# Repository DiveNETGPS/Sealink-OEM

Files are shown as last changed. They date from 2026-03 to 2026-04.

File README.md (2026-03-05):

# DiveNET: Sealink-OEM

Repository landing page and navigation.

## Where to start

- Product docs and source bundle: [product/](product/)
- Main product overview: [product/README.md](product/README.md)
- Requirements and options: [product/Sealink-OEM_Requirements_and_Options.md](product/Sealink-OEM_Requirements_and_Options.md)
- Integrator/testing process guide: [product/integrations/PLATFORM_INTEGRATOR_GUIDE.md](product/integrations/PLATFORM_INTEGRATOR_GUIDE.md)

## Repository layout

- `product/` contains the current documentation and integration content.
- Root-level build/release scripts (`*.bat`, `*.spec`, `VERSION.txt`) are packaging utilities.
- `release/` and `release_assets/` hold generated/customer-facing distribution assets.

---
Questions or support? Contact DiveNET: support@divenetgps.com
Last updated: March 2026

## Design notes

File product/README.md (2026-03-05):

# DiveNET: Sealink-OEM Subsea Wireless Modem

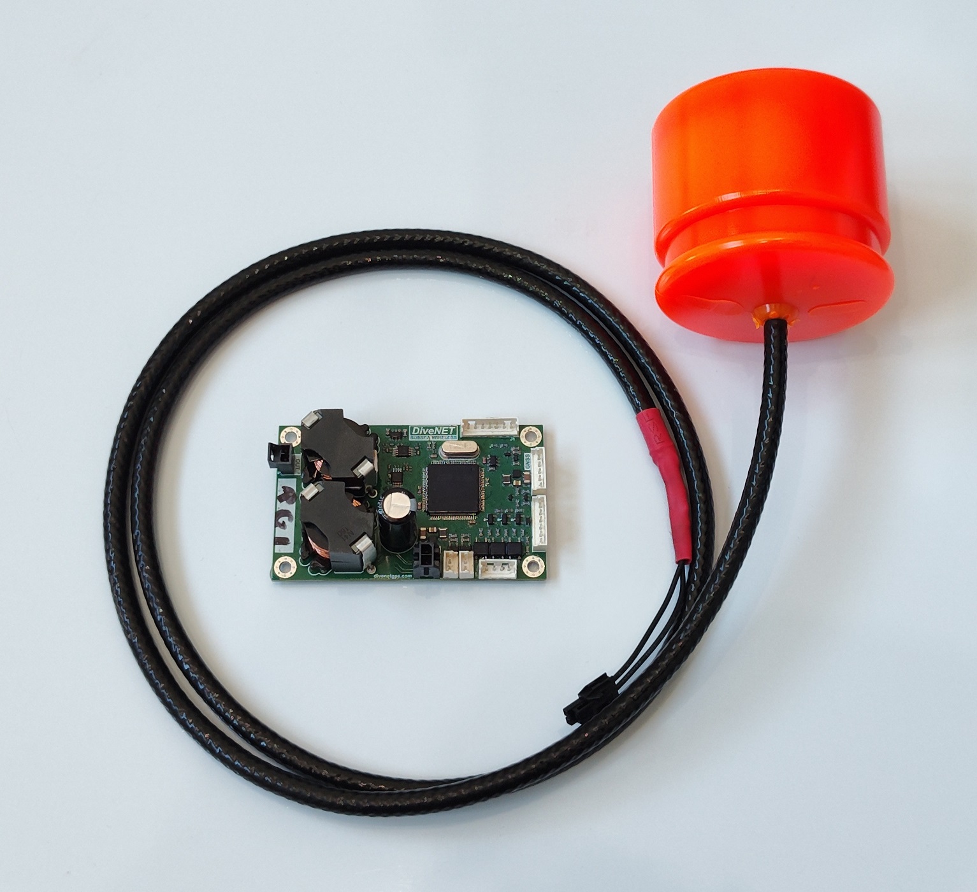
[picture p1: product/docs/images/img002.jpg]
Sealink-OEM


**Sealink-OEM** is a compact, high-reliability underwater acoustic modem and communication platform produced by DiveNET Subsea Wireless (Beringia Enterprises LLC).

### Key Features
- Extremely compact PCB: 73.5 mm × 44 mm
- Reliable long-range communication
- Multi-mode functionality
- Communication envelope up to 3,000 m / 1,000 m depth (transducer-dependent)
- Up to 634 bps bandwidth
- 255 logical addresses (responders) and 20 code channels
- 9600 bps UART interface (3.3 V logic)
- Built-in support for external pressure/temperature sensor (I²C on XP6)
- GNSS and RF module expansion
- Built-in Time-of-Flight (ToF) ranging with ~0.15 m resolution
- Tx/Rx strobe output for external timestamp capture
- Designed to power subsea IoT and professional ROV/AUV/Diver applications

### Primary Specifications
- **Board size**: 73.5 mm × 44 mm
- **Power**: +12 V DC nominal
- **Logic level**: 3.3 V UART (0–3.3 V)
- **UART settings**: 9600 baud, 8N1 (default)
- **Connectors**: Molex Mini-Fit Jr. series
- **Operating modes**: Transparent channel, Command mode, Packet mode
- **Ranging**: ~0.15 m resolution (acoustic detection limit)

### Transducer Options
Sealink-OEM supports interchangeable transducers for different mission profiles:

1. **1,000 m acoustic range / 600 m depth rating**  
   - Model: SW-T100  
   - Max slant range: ~1,000 m (line-of-sight)  
   - Max operational depth: 600 m  
   - [Specification]

2. **3,000 m acoustic range / 300 m depth rating**  
   - Model: SW-T200    
   - Max slant range: ~3,000 m (line-of-sight)  
   - Max operational depth: 300 m  
   - [Specification]

3. **3,000 m acoustic range / 1,000 m depth rating**  
   - Model: SW-T300    
   - Max slant range: ~3,000 m (line-of-sight)  
   - Max operational depth: 1,000 m  
   - [Specification]

### Quick Start
1. Connect power (+12 V nominal) to XP2 and transducer to XP1.  
2. Use any serial terminal (PuTTY, Tera Term, CoolTerm, minicom) at 9600 8N1.  
3. Send `$PUWV2,0,0,0*2A` to ping a remote unit.  
- Expect an immediate `$PUWV0` automatic acknowledgement response (e.g., `$PUWV0,2,0*XX`) confirming command acceptance. If errCode ≠ 0, check setup.
4. Receive main response `$PUWV3,0,0,propTime,MSR*hh` → approximate range = propTime (seconds) × 1500 (m/s).  
5. Refine with correct sound speed (adjust for temperature/salinity/depth).

Full documentation → see [docs](docs) folder.

### Documentation Map

- [Documentation Index](docs/README.md)

### Modem Documentation

- [Getting Started](docs/Sealink-OEM_Getting_Started.md)
- [Pinout & Interface](docs/Sealink-OEM_Pinout_and_Interface.md)
- [Communication Protocol](docs/Sealink-OEM_Communication_Protocol.md)
- [Basic Ranging Guide](docs/Sealink-OEM_Basic_Ranging_Guide.md)
- [Technical Drawing](docs/Sealink-OEM_Technical_Drawing.pdf)

### Utility App Documentation

- [Sealink-OEM Utility App Guide](docs/Sealink-OEM_Utility_App_Guide.md)
- [CLI test script](resources/uart-getRange.py)

---
Questions or support? Contact DiveNET: support@divenetgps.com
Last updated: March 2026

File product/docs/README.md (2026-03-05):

# Sealink-OEM Documentation Index

Use this index to navigate modem documentation and software tooling guides.

## Modem Fundamentals

- [Getting Started](Sealink-OEM_Getting_Started.md)
- [Pinout and Interface](Sealink-OEM_Pinout_and_Interface.md)
- [Communication Protocol](Sealink-OEM_Communication_Protocol.md)
- [Basic Ranging Guide](Sealink-OEM_Basic_Ranging_Guide.md)
- [Technical Drawing (PDF)](Sealink-OEM_Technical_Drawing.pdf)

## Utility App and Tools

- [Sealink-OEM Utility App Guide](Sealink-OEM_Utility_App_Guide.md)
- [CLI test script (uart-getRange.py)](../resources/uart-getRange.py)

## Integration References

- [Integrator Platform Guide](../integrations/PLATFORM_INTEGRATOR_GUIDE.md)
- [Arduino Example](../integrations/arduino/SealinkOEM_Basic.ino)
- [Raspberry Pi CLI Runner](../integrations/raspberry-pi/run_sealink_cli.sh)

---
Questions or support? Contact DiveNET: support@divenetgps.com
Last updated: March 2026

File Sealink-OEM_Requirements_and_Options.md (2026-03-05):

# Sealink-OEM – Requirements and Options

This root-level file is retained for compatibility.

## Minimum Host Requirements (Summary)

### Windows Native Utility Package
- Package: Sealink-OEM (Windows Utility package)
- OS: Windows 10 or Windows 11 (64-bit)
- Python: not required for packaged `.exe` execution
- Serial access: at least one available `COM` port through compatible USB-UART bridge or host UART interface

### Integrator / CLI Workflow
- Package: Sealink-Integrator-Pack (CLI/Integration)
- Python: 3.10 or newer (3.10–3.12 recommended)
- `pip` and dependency install from `resources/requirements.txt` (includes `pyserial`)
- Linux/Raspberry Pi workflow uses `integrations/raspberry-pi/run_sealink_cli.sh`

Current maintained version:

- [product/Sealink-OEM_Requirements_and_Options.md](product/Sealink-OEM_Requirements_and_Options.md)

Use the file above for current requirements and options guidance.

---
Questions or support? Contact DiveNET: support@divenetgps.com
Last updated: March 2026

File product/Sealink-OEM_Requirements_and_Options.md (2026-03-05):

# Sealink-OEM – Requirements and Options

This document summarizes the **mandatory requirements** for operating the Sealink-OEM modem and the **optional/configurable elements** available to adapt it to different applications.

## Mandatory Requirements

### Host Software Requirements (Native App and Integrator Workflows)

#### Windows Native Utility Package
- Package: Sealink-OEM (Windows Utility package)
- OS: Windows 10 or Windows 11 (64-bit)
- Python: not required for packaged `.exe` execution
- Serial access: at least one available `COM` port through compatible USB-UART bridge or host UART interface

#### Integrator / CLI Workflow
- Package: Sealink-Integrator-Pack (CLI/Integration)
- Python: 3.10 or newer (3.10–3.12 recommended)
- Required Python dependency set from `resources/requirements.txt` (includes `pyserial`)
- Linux/Raspberry Pi workflow requires shell access for `integrations/raspberry-pi/run_sealink_cli.sh`

### Power Supply
- Voltage: +12 V DC nominal  
- Range: 12 V minimum – 14 V maximum (±0.3 V tolerance)  
- Connector: XP2 (Molex 43045-0212)  
  - Pin 1: GND  
  - Pin 2: +12 V  
- **Caution**: Exceeding 14.3 V or dropping below 12 V may damage the board or cause unreliable operation.

### Communication Interface
- UART: 9600 baud, 8 data bits, no parity, 1 stop bit (8N1)  
- Logic level: 0–3.3 V (do not exceed 3.3 V on data lines)  
- Connector: XP5 (Molex 53253-0470)  
  - Pin 1: TxD  
  - Pin 2: RxD  
  - Pin 3: SVC/CMD (strobe output in firmware ≥1.2.0)  
  - Pin 4: GND  
- **Caution**: Applying >5.3 V to UART lines will cause automatic shutdown or permanent damage.

### Acoustic Transducer
- Must be connected to XP1 (Molex 105309-1102)  
- Use only the transducer supplied with the device or a compatible model (SW-T100, SW-T200, SW-T300)  
- **Caution**: Using a non-compatible antenna/transducer will result in damage to the board.

### Operating Environment
- The modem is designed for underwater/submerged use.  
- Dry-land testing is supported only for basic functional verification (transducers within ~6 inches).  
- **Note**: Dry-land operation does not guarantee payload data integrity.

### Firmware
- Minimum version: ≥1.2.0 (command mode always enabled, SVC/CMD repurposed as strobe output)

## Optional / Configurable Elements

### Transducer Selection
Choose based on range vs. depth trade-off:

| Model | Max Acoustic Range (slant) | Max Operational Depth | Notes |
|---|---|---|---|
| SW-T100 | ~1,000 m | 600 m | Best for moderate range / deeper ops |
| SW-T200 | ~3,000 m | 300 m | Balanced range / depth |
| SW-T300 | ~3,000 m | 1,000 m | Maximum range + maximum depth |

### Expansion Modules
- **XP6 – Pressure Sensor**  
  - Designed specifically for KELLER 4LD series (I²C)  
  - Pinout: +3.3 V, SDA, SCL, GND  
  - **Caution**: Connecting any other device is prohibited and may cause permanent failure.

- **XP7 – GNSS Module**  
  - +3.3 V, 1PPS, TxD, RxD, GND  
  - For optional position/time synchronization

- **XP8 – RF Module**  
  - +5 V, ENABLE, TxD, RxD, GND, SET  
  - For optional surface RF gateway/relay

### LED Indicators
- Connected via XP3/XP4 (LED +, LED -)  
- Can be used for status visualization (power, Tx/Rx activity, etc.)

### Sound Speed for Ranging
- Default in examples/scripts: 1500 m/s  
- Recommended to adjust for actual conditions (temperature, salinity, depth).  
- See [Basic Ranging Guide](docs/Sealink-OEM_Basic_Ranging_Guide.md) for reference table.

### Protocol & Addressing
- Up to 255 logical addresses (0–254 usable)  
- Up to 20 code channels  
- Configurable via $PUWV1 sentences (address, channel, baud rate, etc.)

---
Questions or support? Contact DiveNET: support@divenetgps.com
Last updated: March 2026

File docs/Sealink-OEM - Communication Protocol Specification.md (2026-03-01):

# DiveNET: Sealink-OEM Subsea Wireless Modem  
## Communication Protocol Specification v1.0

**Document Date**: February 2026  
**Revision**: 1.0  
**Copyright**: © 2026 DiveNET Subsea Wireless – Beringia Enterprises LLC. All rights reserved.

## Contents

1. Introduction  
   1.1 Physical Layer  
   1.2 NMEA0183 Protocol Standard  

2. Sealink Commands & Responses  

   2.1 ACK Response  
   2.2 Settings Write  
   2.3 Remote Code Request  
   2.4 Remote Code Response  
   2.5 Remote Timeout  
   2.6 Remote Asynchronous Input  
   2.7 Ambient Data Configuration  
   2.8 Ambient Data Output  
   2.9 Device Information Request  
   2.10 Device Information  
   2.11 Packet Mode Settings Read  
   2.12 Packet Mode Settings  
   2.13 Packet Mode Settings Write  
   2.14 Packet Send  
   2.15 Packet Failed  
   2.16 Packet Delivered  
   2.17 Packet Received  
   2.18 Remote Request (Logical Addressing)  
   2.19 Remote Timeout (Logical Addressing)  
   2.20 Remote Response (Logical Addressing)  
   2.21 Incremental Data Configuration (USBL models only)  
   2.22 Incremental Data Output (USBL models only)  

3. Operating Modes  

   3.1 Transparent Channel Mode  
   3.2 Command Mode  
   3.3 Packet Mode  

4. Identifiers  

   4.1 Error Codes  
   4.2 Remote Command IDs  

5. Appendix  

   5.1 Command Mode Examples  
      5.1.1 Example 1 – Requesting Device Information  
      5.1.2 Example 2 – Requesting Remote Depth  
      5.1.3 Example 3 – Ambient Data Configuration  
      5.1.4 Example 4 – Enabling Packet Mode  
      5.1.5 Example 5 – Sending a Packet  
   5.2 Configuration Recipes  

## 1. Introduction

### 1.1 Physical Layer

The Sealink-OEM modem uses an asynchronous RS-232 compatible UART interface with 3.3 V logic levels. Connection requires four wires: Tx (transmit), Rx (receive), Vcc (+3.3 V logic supply), and GND. Maximum guaranteed cable length without repeaters or converters is 2 meters.

**Default UART settings**:
- Baud rate: 9600 bit/s  
- Data bits: 8  
- Stop bits: 1  
- Parity: None  
- Hardware flow control: None  

**Power supply**: +12 V DC nominal (12 V min – 14 V ±0.3 V max)  
**Warning**: Logic lines are 0–3.3 V only. Voltages >5.3 V may cause shutdown or permanent damage.

The modem defaults to Command Mode on power-up.

### 1.2 NMEA0183 Protocol Standard

The Sealink protocol follows the NMEA0183 text-based format with proprietary extensions. All messages are ASCII, start with `$`, use comma separators, and end with `*` + two-digit hex checksum + `<CR><LF>`.

**Sentence example**:
`$PUWV0,1,0*36<CR><LF>`

**Structure**:
- `$` – sentence start  
- `P` – Proprietary  
- `UWV` – manufacturer identifier
- Sentence identifier (e.g. `0`, `2`, etc.)  
- `,` – parameter separator  
- `*` – checksum separator  
- `hh` – two-digit hex checksum (XOR of all bytes from after `$` to before `*`)  
- `<CR><LF>` – end of sentence (hex 0x0D 0x0A)

## 2. Sealink Commands & Responses

All sentences use the `$PUWV` prefix.

### 2.1 ACK Response
Device acknowledgement.

**Format**: `$PUWV0,cmdID,errCode*hh<CR><LF>`

| Field | Description |
|---|---|
| cmdID | ID of the incoming sentence causing this ACK |
| errCode  | Error code (see 4.1 Error Codes) |

### 2.2 Settings Write
Write new configuration settings.

**Format**: `$PUWV1,txChID,rxChID,salinityPSU,isCmdMode,isACKOnTXFinished,gravityAcc*hh<CR><LF>`

| Field | Description |
|---|---|
| txChID | Transmit code channel ID (0–19) |
| rxChID | Receive code channel ID (0–19) |
| salinityPSU | Water salinity in PSU (e.g. 0 for fresh, 35 for seawater) |
| isCmdMode | 1 = Command mode by default, 0 = Command mode by pin |
| isACKOnTXFinished | 1 = ACK sent after TX buffer empty, 0 = no ACK |
| gravityAcc | Local gravity acceleration (m/s², typical 9.77–9.84) |

### 2.3 Remote Code Request
Send a short command to a remote modem.

**Format**: `$PUWV2,txChID,rxChID,rcCmdID*hh<CR><LF>`

| Field | Description |
|---|---|
| txChID | Transmit code channel ID |
| rxChID | Receive code channel ID for the request |
| rcCmdID | Remote command ID (see 4.2 Remote Command IDs) |

### 2.4 Remote Code Response
Reply from remote modem.

**Format**: `$PUWV3,txChID,rcCmdID,propTime,MSR[,Value][,Azimuth]*hh<CR><LF>`

| Field | Description |
|---|---|
| txChID | Transmit code channel used |
| rcCmdID | Echo of requested command ID |
| propTime  | Propagation time in seconds (one-way) |
| MSR | Mean signal ratio (dB) |
| Value | Requested value (e.g. depth, temperature) |
| Azimuth | Horizontal angle of arrival (USBL models only) |

### 2.5 Remote Timeout
No reply from remote modem.

**Format**: `$PUWV4,txChID,rcCmdID*hh<CR><LF>`

| Field | Description |
|---|---|
| txChID | Transmit code channel used |
| rcCmdID | Requested command ID |

### 2.6 Remote Asynchronous Input
Incoming message from remote modem.

**Format**: `$PUWV5,rcCmdID,MSR[,Azimuth]*hh<CR><LF>`

| Field | Description |
|---|---|
| rcCmdID | Command ID (see 4.2) |
| MSR | Mean signal ratio (dB) |
| Azimuth | Horizontal angle of arrival (USBL models only) |

### 2.7 Ambient Data Configuration
Configure automatic transmission of ambient parameters and supply voltage.

**Format**: `$PUWV6,isSaveToFlash,PeriodMs,IsPressure,IsTemperature,IsDepth,IsVCC*hh<CR><LF>`

| Field | Description |
|---|---|
| isSaveToFlash | 1 = save to flash, 0 = do not save |
| PeriodMs | Output period (ms): 0 = disabled, 1 = tandem, 500–60000 = timed |
| IsPressure | 1 = enable pressure output, 0 = disable |
| IsTemperature | 1 = enable temperature output, 0 = disable |
| IsDepth | 1 = enable depth output, 0 = disable |
| IsVCC | 1 = enable supply voltage output, 0 = disable |

### 2.8 Ambient Data Output
Ambient parameters and supply voltage readings.

**Format**: `$PUWV7,Pressure_mBar,Temperature_C,Depth_m,VCC_V*hh<CR><LF>`

| Field | Description |
|---|---|
| Pressure_mBar | Pressure in millibars |
| Temperature_C | Temperature in °C |
| Depth_m | Depth in meters |
| VCC_V | Supply voltage in volts |

### 2.9 Device Information Request
Request device information.

**Format**: `$PUWV?,reserved*hh<CR><LF>`

| Field | Description |
|---|---|
| reserved  | Set to 0 |

### 2.10 Device Information
Device information response.

**Format**: `$PUWV!,serialNumber,systemMoniker,systemVersion,coreMoniker,coreVersion,acBaudrate,rxChID,txChID,maxChannels,styPSU,isPTS,isCmdMode*hh<CR><LF>`

| Field | Description |
|---|---|
| serialNumber | Device serial number |
| systemMoniker | System name |
| systemVersion | System version |
| coreMoniker | Communication subsystem name |
| coreVersion | Communication subsystem version |
| acBaudrate | Acoustic channel baud rate (bit/s) |
| rxChID | Receive code channel ID |
| txChID | Transmit code channel ID |
| maxChannels | Total number of code channels |
| styPSU | Salinity setting (PSU) |
| isPTS | 1 = pressure/temperature sensor present |
| isCmdMode | 1 = Command mode by default |

### 2.11 Packet Mode Settings Read
Read current packet mode settings. The modem responds with IC_D2H_PT_SETTINGS.

**Format**: `$PUWVD,reserved*hh<CR><LF>`

| Field | Description |
|---|---|
| reserved  | Set to 0 |

### 2.12 Packet Mode Settings
Current packet mode configuration.

**Format**: `$PUWVE,isPTMode,ptLocalAddress*hh<CR><LF>`

| Field | Description |
|---|---|
| isPTMode | 1 = packet mode enabled, 0 = disabled |
| ptLocalAddress | Local modem address (0–254) |

**Note**: Since firmware 1.20, packet mode is active whenever the modem is in Command Mode — no separate enable flag is required.

### 2.13 Packet Mode Settings Write
Set new packet mode settings. The modem responds with IC_D2H_PT_SETTINGS.

**Format**: `$PUWVF,isSaveToFlash,isPTMode,ptLocalAddress*hh<CR><LF>`

| Field | Description |
|---|---|
| isSaveToFlash | 1 = save to flash, 0 = do not save |
| isPTMode | 1 = enable packet mode, 0 = disable |
| ptLocalAddress  | Local modem address (0–254) |

**Note**: isPTMode is legacy (firmware 1.20+ ignores it — Command Mode enables packet mode automatically).

### 2.14 Packet Send
Send a data packet in packet mode.

**Format**: `$PUWVG,target_ptAddress,maxTries,dataPacket*hh<CR><LF>`

| Field | Description |
|---|---|
| target_ptAddress | Destination address (0–254 unicast, 255 broadcast) |
| maxTries | Maximum retransmission attempts (0–255; empty = default 255) |
| dataPacket | Hex bytes with `0x` prefix (e.g. `0x313233` for “123”). Max 64 bytes. Empty = cancel current transfer. |

### 2.15 Packet Failed
Transmission failed (max tries exceeded or other error).

**Format**: `$PUWVH,target_ptAddress,maxTries,dataPacket*hh<CR><LF>`

| Field | Description |
|---|---|
| target_ptAddress | Destination address |
| maxTries | Number of attempts made |
| dataPacket | Hex bytes sent (same as request) |

### 2.16 Packet Delivered
Packet successfully delivered with acknowledgement.

**Format**: `$PUWVI,target_ptAddress,maxTries[,azimuth],dataPacket*hh<CR><LF>`

| Field | Description |
|---|---|
| target_ptAddress | Destination address |
| maxTries | Number of attempts made |
| azimuth | Horizontal angle of arrival (USBL models only; empty otherwise) |
| dataPacket | Hex bytes sent (same as request) |

### 2.17 Packet Received
Incoming packet from another modem.

**Format**: `$PUWVJ,sender_ptAddress[,azimuth],dataPacket*hh<CR><LF>`

| Field | Description |
|---|---|
| sender_ptAddress | Sender address (0–254) |
| azimuth | Horizontal angle of arrival (USBL models only; empty otherwise) |
| dataPacket | Received hex bytes (max 64) |

### 2.18 Remote Request (Logical Addressing)
Request a parameter from a remote modem using logical addressing.

**Format**: `$PUWVK,target_ptAddress,dataID*hh<CR><LF>`

| Field | Description |
|---|---|
| target_ptAddress | Remote modem address (0–254) |
| dataID | Requested parameter: 0 = depth, 1 = temperature, 2 = supply voltage |

### 2.19 Remote Timeout (Logical Addressing)
No response to logical-addressed remote request.

**Format**: `$PUWVL,target_ptAddress,dataID*hh<CR><LF>`

| Field | Description |
|---|---|
| target_ptAddress | Remote modem address |
| dataID | Requested parameter ID |

### 2.20 Remote Response (Logical Addressing)
Response to logical-addressed remote request.

**Format**: `$PUWVM,target_ptAddress,dataID,dataValue,pTime[,azimuth]*hh<CR><LF>`

| Field | Description |
|---|---|
| target_ptAddress | Remote modem address |
| dataID | Requested parameter ID |
| dataValue | Returned value (e.g. depth in m, temp in °C, voltage in V) |
| pTime | Propagation time in seconds |
| azimuth | Horizontal angle of arrival (USBL models only; empty otherwise) |

### 2.21 Incremental Data Configuration (USBL models only)
Configure output of pitch and roll data.

**Format**: `$PUWV8,isSaveToFlash,PeriodMs*hh<CR><LF>`

| Field | Description |
|---|---|
| isSaveToFlash | 1 = save to flash, 0 = do not save |
| PeriodMs | Output period (ms): 0 = disabled, 1 = tandem, 500–60000 = timed |

### 2.22 Incremental Data Output (USBL models only)
Pitch and roll readings.

**Format**: `$PUWV9,reserved,Pitch,Roll*hh<CR><LF>`

| Field | Description |
|---|---|
| reserved  | Reserved (empty) |
| Pitch | Device pitch in degrees |
| Roll | Device roll in degrees |
### 3. Operating Modes

3.1 Transparent Channel Mode  
In Transparent mode, all data from the host is sent unchanged over the acoustic channel and received unchanged by another modem on the same code channel.

3.2 Command Mode  
Command mode allows configuration, ranging, and advanced control. Modems analyze incoming data only in this mode.  
- Default on power-up  
- Can be set permanently via Settings Write (isCmdMode = 1)  
- SVC/CMD pin (XP5 Pin 3) becomes a strobe output for Tx/Rx timing

3.3 Packet Mode  
Packet mode enables reliable data transfer up to 64 bytes, including arbitrary data, with guaranteed delivery and acknowledgement.  
- Active automatically in Command Mode (no separate enable needed since firmware 1.20+)  
- Supports 255 logical addresses (0–254 unicast, 255 broadcast)  
- See commands 2.11–2.20

### 4. Identifiers

4.1 Error Codes

| Code | Value | Description |
|---|---|---|
| LOC_ERR_NO_ERROR | 0 | Request accepted |
| LOC_ERR_INVALID_SYNTAX | 1 | Syntax error |
| LOC_ERR_UNSUPPORTED | 2 | Request not supported |
| LOC_ERR_TRANSMITTER_BUSY | 3 | Transmitter busy |
| LOC_ERR_ARGUMENT_OUT_OF_RANGE| 4 | Parameter out of range |
| LOC_ERR_INVALID_OPERATION | 5 | Invalid operation |
| LOC_ERR_UNKNOWN_FIELD_ID | 6 | Unknown field ID |
| LOC_ERR_VALUE_UNAVAILABLE | 7 | Value not available |
| LOC_ERR_RECEIVER_BUSY | 8 | Receiver busy |
| LOC_ERR_TX_BUFFER_OVERRUN | 9 | TX buffer overrun |
| LOC_ERR_CHKSUM_ERROR | 10 | Checksum error |
| LOC_ACK_TX_FINISHED | 11 | TX buffer empty |
| LOC_ACK_BEFORE_STANDBY | 12 | Entering standby |
| LOC_ACK_AFTER_WAKEUP | 13 | Exited standby |
| LOC_ERR_SVOLTAGE_TOO_HIGH | 14 | Supply voltage too high |

4.2 Remote Command IDs

| Command | Value | Description |
|---|---|---|
| RC_PING | 0 | Ping |
| RC_PONG | 1 | Pong |
| RC_DPT_GET | 2 | Get remote depth |
| RC_TMP_GET | 3 | Get remote temperature |
| RC_BAT_V_GET | 4 | Get remote battery voltage |
| RC_ERR_NSUP | 5 | Request not supported |
| RC_ACK | 6 | Request accepted |
| RC_USR_CMD_000–007  | 7–14  | User-defined commands |
| RC_MSG_ASYNC_IN | 16 | Incoming transparent message |

### 5. Appendix

5.1 Command Mode Examples  
- Examples use correct checksums and <CR><LF> terminators. Replace `hh` with actual calculated checksum.
- Examples use "<<" to indicate outbound messages/querries and ">>" to indicate inbound messages/responses.

**5.1.1 Example 1 – Requesting Device Information**  

`<< $PUWV?,0*27<CR><LF>`

`>> $PUWV!,3A001E000E51363437333330,SEALINK,1.00,SEALINK_CORE,1.01,9600,0,0,20,35.0,1,1*XX<CR><LF>`

**Explanation**:  

- PUWV? = IC_H2D_DINFO_GET  
- Response includes serial number, system/core versions, baud rate, channel IDs, salinity, sensor presence, and Command Mode status.

**5.1.2 Example 2 – Requesting Remote Depth**  

`<< $PUWV2,0,0,2*28<CR><LF>`

`>> $PUWV0,2,036<CR><LF>` (ACK: request accepted, no error)

`>> $PUWV3,0,2,0.667,25.40,12.34XX<CR><LF>` (response: propTime=0.667 s, depth=12.34 m)

**Explanation**:  

- PUWV2 = IC_H2D_RC_REQUEST  
- 2 = RC_DPT_GET  
- Response: propagation time (s), signal quality (MSR in dB), and remote depth (m)

**5.1.3 Example 3 – Setting up the Ambient Data Configuration**

`<< $PUWV6,1,1000,1,1,1,1*03<CR><LF>`

`>> $PUWV0,6,032<CR><LF>` (ACK: request accepted, no error)

`>> $PUWV7,1025.2,29.9,-0.014,5.018<CR><LF>`  (periodic ambient data)

`>> $PUWV7,1026.3,29.9,-0.002,5.0*1D<CR><LF>`  (next reading)

**Explanation**:  

- PUWV6 = IC_H2D_AMB_DTA_CFG  
- 1 = save to flash  
- 1000 = 1-second interval  
- 1,1,1,1 = enable pressure, temperature, depth, VCC  
- PUWV7 = IC_D2H_AMB_DTA (pressure in mBar, temperature in °C, depth in m, VCC in V)

**5.1.4 Example 4 – Enabling Packet Mode**  

`<< $PUWVF,1,1,0*5E<CR><LF>`

`>> $PUWVE,1,0*40<CR><LF>`

**Explanation**:  

- PUWVF = IC_H2D_PT_SETTINGS_WRITE  
- 1 = save to flash  
- 1 = enable packet mode  
- 0 = local modem address  
- PUWVE = IC_D2H_PT_SETTINGS (confirms packet mode enabled, address 0)

**Note**: Since firmware 1.20+, packet mode is active in Command Mode — no separate enable required.

**5.1.5 Example 5 – Sending a Packet in Packet Mode and Receiving Acknowledgement**  

`<< $PUWVG,0,8,0x313233*2C<CR><LF>`

`>> $PUWV0,G,043<CR><LF>` (ACK: request accepted, no error)

`>> $PUWVI,0,1,,0x31323307<CR><LF>` (packet delivered successfully)
  
**Explanation**:  

- PUWVG = IC_H2D_PT_SEND  
- 0 = target address  
- 8 = max attempts  
- 0x313233 = hex bytes for "123"  
- PUWVI = IC_D2H_PT_DLVRD (0 = target, 1 = attempts, empty = no azimuth)

**5.1.6 Example 6 – Receiving an Incoming Packet**  

`>> $PUWVJ,42,,0x48656C6C6F*XX<CR><LF>`

**Explanation**:  

- PUWVJ = IC_D2H_PT_RCVD  
- 42 = sender address  
- (empty) = no azimuth  
- 0x48656C6C6F = hex bytes for "Hello"  

No host action required — incoming packet is delivered automatically.

**5.1.7 Example 7 – Requesting Remote Temperature (Logical Addressing)**  

`<< $PUWVK,10,1*XX<CR><LF>`

`>> $PUWVM,10,1,28.50,0.667,XX<CR><LF>` (success)

`>> $PUWVL,10,1XX<CR><LF>` (timeout)

**Explanation**:  

- PUWVK = IC_H2D_PT_ITG  
- 10 = target address  
- 1 = dataID (temperature)  
- PUWVM = IC_D2H_PT_ITG_RESP (temperature 28.50 °C, propTime 0.667 s)  
- PUWVL = IC_D2H_PT_ITG_TMO (timeout)

**5.1.8 Example 8 – Enabling Automatic Ambient Data Output (1-second interval)**  

`<< $PUWV6,1,1000,1,1,1,1*03<CR><LF>`

`>> $PUWV0,6,032<CR><LF>` (ACK: request accepted, no error)

`>> $PUWV7,1025.2,29.9,-0.014,5.018<CR><LF>` (periodic output)

`>> $PUWV7,1026.3,29.9,-0.002,5.0*1D<CR><LF>`

**Explanation**:  

- PUWV6 = IC_H2D_AMB_DTA_CFG  
- 1 = save to flash  
- 1000 ms interval  
- 1,1,1,1 = enable pressure, temperature, depth, VCC

**5.1.9 Example 9 – Requesting Device Information (Alternative Syntax)**  

`<< $PUWV?,0*27<CR><LF>`

`>> $PUWV!,3A001E000E51363437333330,SEALINK,1.00,SEALINK_CORE,1.01,9600,0,0,20,35.0,1,1*XX<CR><LF>`

**Explanation**:  

- Same as 5.1.1 — included here for completeness. Shows legacy syntax still works.

### 5.2 Configuration Recipes

1. **Set default settings (fresh water, Command mode disabled)**  
`$PUWV1,0,0,0.0,0,0,9.8067*XX<CR><LF>`

2. **Enable Command mode by default, seawater salinity**  
`$PUWV1,0,0,35.0,1,0,9.8067*XX<CR><LF>`

3. **Disable automatic ambient data output**  
`$PUWV6,0,0,0,0,0,0*32<CR><LF>`

5. **Enable ambient data every 5 seconds (pressure + temperature only)**  
`$PUWV6,0,5000,1,1,0,0*XX<CR><LF>`

7. **Request local depth (basic)**  
`$PUWV2,0,0,2*28<CR><LF>`

(Checksums must be calculated correctly before sending.)

___
Questions or support? Contact support@divenetgps.com

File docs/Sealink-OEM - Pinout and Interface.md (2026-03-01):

# DiveNET: Sealink-OEM Pinout & Interface

**Board**: DiveNET Sealink-OEM v1.0  
**Dimensions**: 73.5 mm × 44 mm  
**Power**: +12 V nominal (12 V min – 14 V ±0.3 V max) on XP2  
**UART**: 9600 8N1 (9600 baud, 8 data bits, no parity, 1 stop bit)  
**Caution**: UART lines (XP5) are 0–3.3 V logic only. Higher voltages (>5.3 V) will cause shutdown or permanent damage.

## Connector Overview

| Connector | Type | Purpose | Molex Part Number |
|---|---|---|---|
| XP1 | Antenna | Acoustic transducer / antenna | 105309-1102 |
| XP2 | Main Power | +12 V input | 43045-0212 |
| XP3, XP4  | LED | Status LED output | 53253-0270 |
| XP5 | UART (0–3.3 V) | Serial control & data | 53253-0470 |
| XP6 | External Pressure Sensor | I²C sensor interface | 53253-0570 |
| XP7 | GNSS Module | Positioning / timing | 53253-0570 |
| XP8 | RF Module | Radio / extended comms | 53253-0670 |

## Detailed Pinouts

### XP1 – Antenna / Transducer
| Pin | Signal | Description |
|-----|---|---|
| 1 | ANT + | Transducer positive |
| 2 | ANT - | Transducer negative |

**Note**: Use only the supplied transducer/antenna. Other types may damage the board.

### XP2 – Main Power
| Pin | Signal | Description |
|-----|---|---|
| 1 | GND | Ground |
| 2 | +12V | Power input (12–14 V) |

### XP3 & XP4 – LED
| Pin | Signal | Description |
|-----|---|---|
| 1 | LED+ | LED positive |
| 2 | LED- | LED negative |

### XP5 – UART (0–3.3 V)
| Pin | Signal | Direction | Description |
|-----|---|---|---|
| 1 | TxD | Output | Modem → Host data |
| 2 | RxD | Input | Host → Modem data |
| 3 | SVC/CMD | Output | Strobe pulses (Tx start & Rx detect) |
| 4 | GND | - | Ground |

**Note**: SVC/CMD pin outputs short TTL pulses in firmware for external ToF timestamping.

### XP6 – External Pressure Sensor (I²C)
| Pin | Signal | Direction | Description |
|-----|---|---|---|
| 1 | +3.3V | Output | 3.3 V supply |
| 5 | SDA | Bidirectional | I²C data line |
| 6 | SCL | Output | I²C clock |
| 7 | GND | - | Ground |

**Note**: Designed for KELLER 4LD pressure/temperature sensor only.

### XP7 – GNSS Module
| Pin | Signal | Direction | Description |
|-----|---|---|---|
| 1 | +3.3V | Output | 3.3 V supply |
| 2 | 1PPS | Output | 1 Pulse Per Second timing signal |
| 3 | TxD | Output | GNSS data to host |
| 4 | RxD | Input | Host data to GNSS |
| 5 | GND | - | Ground |

### XP8 – RF Module
| Pin | Signal | Direction | Description |
|-----|---|---|---|
| 1 | GND | - | Ground |
| 2 | +5V | Output | 5 V supply |
| 3 | TxENABLE | Input | RF transmit enable |
| 4 | TxD | Output | Data to RF module |
| 5 | RxD | Input | Data from RF module |
| 6 | SET | - | Configuration / mode select |

## Additional Notes
- All UART communication uses 9600 8N1.
- The modem operates in Command Mode by default.
- External pressure sensor (XP6) reports both pressure and temperature if supported.
- For independent ToF, use SVC/CMD strobe on XP5 Pin 3 with external timestamp capture.

___
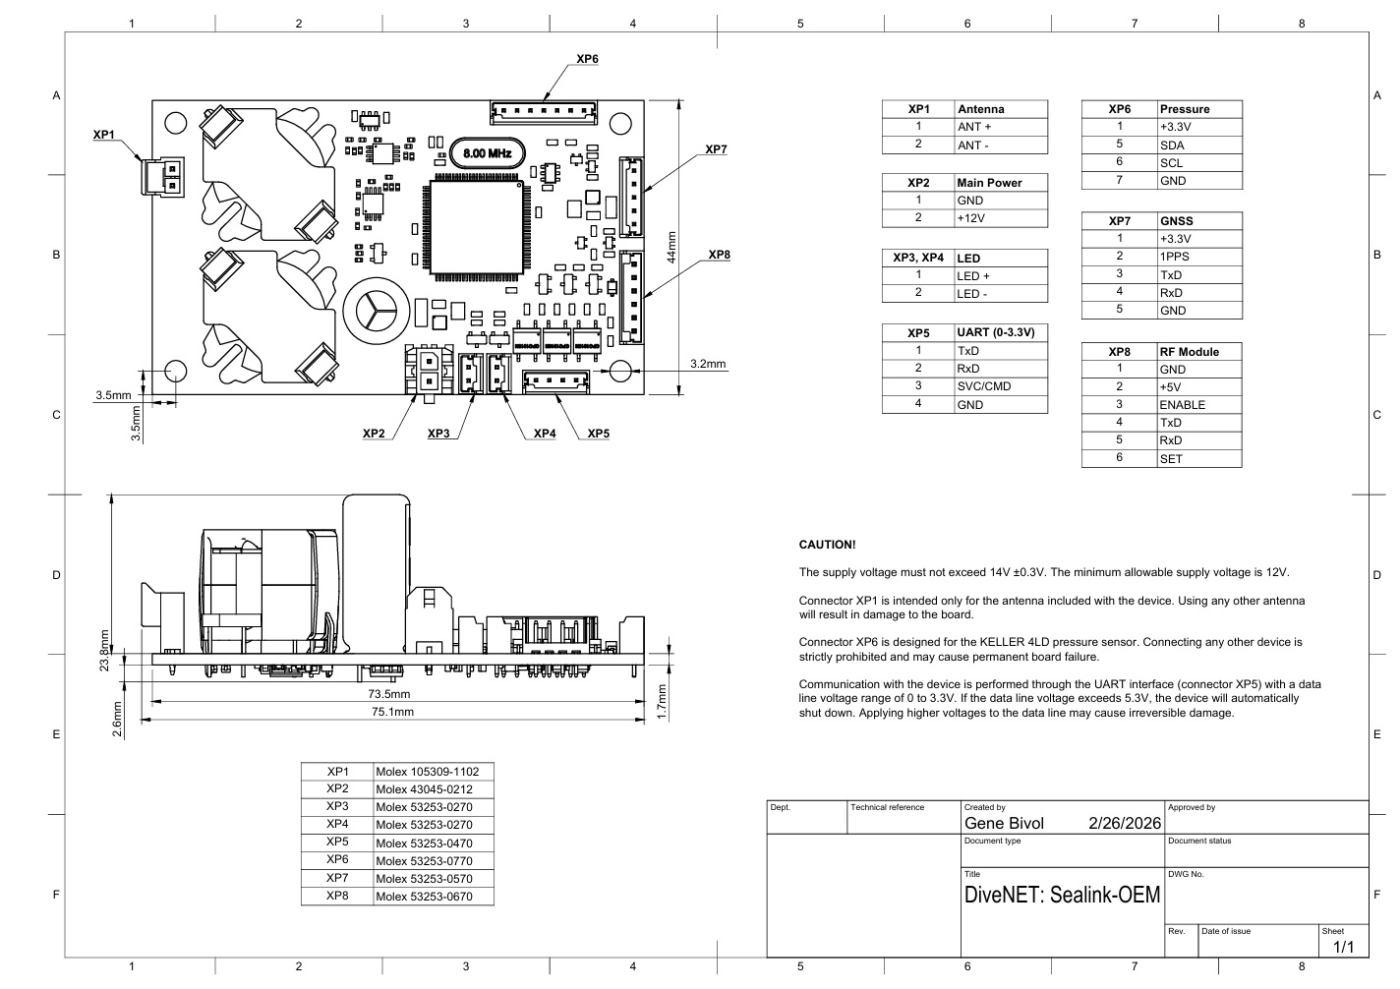
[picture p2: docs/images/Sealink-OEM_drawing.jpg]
Sealink-OEM Technical Drawing

___

© 2026 DiveNET Subsea Wireless – Beringia Enterprises LLC  
All rights reserved.

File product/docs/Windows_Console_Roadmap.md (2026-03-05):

# Sealink OEM Windows Console Roadmap

This document tracks the plan for evolving the Windows host tooling into a full console-first application while keeping current release builds stable.

## Branching strategy

- Stable release line: `main`
- Console development line: `feature/windows-console-app`
- Keep current Utility/Listener release flow unchanged until console parity is reached.

## External references

Primary references for behavior and workflow:

- `https://github.com/ucnl/uWaveCommander`
- `https://github.com/ucnl/uWaveCommander/blob/main/README.md`
- `https://docs.unavlab.com/underwater_acoustic_modems_en.html#uwave`

Observed patterns to replicate:

- Explicit link/connect workflow with modem identity readback.
- Dedicated operations for local sensor streaming.
- Remote short-command test loop behavior.
- Packet mode style operations and diagnostics.
- Operator-friendly guided usage in addition to scriptable control.

## Target console capabilities

### Phase 1: CLI core and parity baseline

- [x] Unified executable entrypoint for Windows console usage.
- [x] Link/connect command (`link`) with port and baud options.
- [x] Device info command (`device-info`) and structured output.
- [x] Remote ping command (`ping`) with channel options.
- [x] Human output and machine-readable JSON output mode.

### Phase 2: Session and workflow ergonomics

- [x] Interactive shell mode (`shell`) with command history.
- [x] Persistent profile support (default port/channels/env values).
- [x] Unified logging (`--log-file`) and verbose diagnostics (`--debug`).
- [x] Command aliases for common workflows.

### Phase 3: Sensor and monitoring features

- [ ] Live monitor command for periodic local/remote telemetry.
- [ ] Sampling interval and timeout controls.
- [ ] CSV logging mode for field collection.
- [ ] Console-friendly status table view.

### Phase 4: Packet and advanced operations

- [ ] Packet mode command group.
- [ ] Logical-addressed request workflows.
- [ ] Reliability and retry policy options.
- [ ] Scenario scripts for repeatable validation tests.

## Release gate to replace current Utility-first workflow

Before replacing current primary workflow, require:

- [ ] All Utility critical commands have console parity.
- [ ] Internal test checklist passes on Windows 10/11.
- [ ] Updated docs for operator and integrator flows.
- [ ] Signed-off migration note in release notes.

## Near-term implementation order

1. Expand `monitor` from scaffold to functional telemetry loop.
2. Add CSV export for monitor and test sessions.
3. Start packet-mode command group design.
4. Add a concise operator command reference page for shell usage.
5. Add response formatting presets for operator vs automation output.

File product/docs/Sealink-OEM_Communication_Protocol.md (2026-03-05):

# DiveNET: Sealink-OEM Subsea Wireless Modem  
## Communication Protocol v1.0

**Document Date**: February 2026  
**Revision**: 1.0  
**Copyright**: © 2026 DiveNET Subsea Wireless – Beringia Enterprises LLC. All rights reserved.

## Contents

- **1.** [Introduction](#1-introduction)  
  - **1.1** [Physical Layer](#11-physical-layer)  
  - **1.2** [NMEA0183 Protocol Standard](#12-nmea0183-protocol-standard)  

- **2.** [Sealink Commands & Responses](#2-sealink-commands--responses)  
  - **2.1** [ACK Response](#21-ack-response)  
  - **2.2** [Settings Write](#22-settings-write)  
  - **2.3** [Remote Code Request](#23-remote-code-request)  
  - **2.4** [Remote Code Response](#24-remote-code-response)  
  - **2.5** [Remote Timeout](#25-remote-timeout)  
  - **2.6** [Remote Asynchronous Input](#26-remote-asynchronous-input)  
  - **2.7** [Ambient Data Configuration](#27-ambient-data-configuration)  
  - **2.8** [Ambient Data Output](#28-ambient-data-output)  
  - **2.9** [Device Information Request](#29-device-information-request)  
  - **2.10** [Device Information](#210-device-information)  
  - **2.11** [Packet Mode Settings Read](#211-packet-mode-settings-read)  
  - **2.12** [Packet Mode Settings](#212-packet-mode-settings)  
  - **2.13** [Packet Mode Settings Write](#213-packet-mode-settings-write)  
  - **2.14** [Packet Send](#214-packet-send)  
  - **2.15** [Packet Failed](#215-packet-failed)  
  - **2.16** [Packet Delivered](#216-packet-delivered)  
  - **2.17** [Packet Received](#217-packet-received)  
  - **2.18** [Remote Request (Logical Addressing)](#218-remote-request-logical-addressing)  
  - **2.19** [Remote Timeout (Logical Addressing)](#219-remote-timeout-logical-addressing)  
  - **2.20** [Remote Response (Logical Addressing)](#220-remote-response-logical-addressing)  
  - **2.21** [Incremental Data Configuration (USBL models only)](#221-incremental-data-configuration-usbl-models-only)  
  - **2.22** [Incremental Data Output (USBL models only)](#222-incremental-data-output-usbl-models-only)  

- **3.** [Operating Modes](#3-operating-modes)  
  - **3.1** [Transparent Channel Mode](#31-transparent-channel-mode)  
  - **3.2** [Command Mode](#32-command-mode)  
  - **3.3** [Packet Mode](#33-packet-mode)  

- **4.** [Identifiers](#4-identifiers)  
  - **4.1** [Error Codes](#41-error-codes)  
  - **4.2** [Remote Command IDs](#42-remote-command-ids)  

- **5.1** [Command Mode Examples](#51-command-mode-examples)
  - **5.1.1** [Example 1 – Requesting Device Information](#511-example-1--requesting-device-information)
  - **5.1.2** [Example 2 – Requesting Remote Depth](#512-example-2--requesting-remote-depth)
  - **5.1.3** [Example 3 – Setting up the Ambient Data Configuration](#513-example-3--setting-up-the-ambient-data-configuration)
  - **5.1.4** [Example 4 – Enabling Packet Mode](#514-example-4--enabling-packet-mode)
  - **5.1.5** [Example 5 – Sending a Packet in Packet Mode and Receiving Acknowledgement](#515-example-5--sending-a-packet-in-packet-mode-and-receiving-acknowledgement)
  - **5.1.6** [Example 6 – Receiving an Incoming Packet](#516-example-6--receiving-an-incoming-packet)
  - **5.1.7** [Example 7 – Requesting Remote Temperature (Logical Addressing)](#517-example-7--requesting-remote-temperature-logical-addressing)
  - **5.1.8** [Example 8 – Enabling Automatic Ambient Data Output (1-second interval)](#518-example-8--enabling-automatic-ambient-data-output-1-second-interval)
  - **5.1.9** [Example 9 – Requesting Device Information (Alternative Syntax)](#519-example-9--requesting-device-information-alternative-syntax)

- **5.2** [Configuration Recipes](#52-configuration-recipes)
  - **1.** [Set default settings (fresh water, Command mode disabled)](#1-set-default-settings-fresh-water-command-mode-disabled)
  - **2.** [Enable Command mode by default, seawater salinity](#2-enable-command-mode-by-default-seawater-salinity)
  - **3.** [Disable automatic ambient data output](#3-disable-automatic-ambient-data-output)
  - **4.** [Enable ambient data every 5 seconds (pressure + temperature only)](#4-enable-ambient-data-every-5-seconds-pressure--temperature-only)
  - **5.** [Request local depth (basic)](#5-request-local-depth-basic)

## 1. Introduction

### 1.1 Physical Layer

The Sealink-OEM modem uses an asynchronous RS-232 compatible UART interface with 3.3 V logic levels. Connection requires four wires: Tx (transmit), Rx (receive), Vcc (+3.3 V logic supply), and GND. Maximum guaranteed cable length without repeaters or converters is 2 meters.

**Default UART settings**:
- Baud rate: 9600 bit/s  
- Data bits: 8  
- Stop bits: 1  
- Parity: None  
- Hardware flow control: None  

**Power supply**: +12 V DC nominal (12 V min – 14 V ±0.3 V max)  
**Warning**: Logic lines are 0–3.3 V only. Voltages >5.3 V may cause shutdown or permanent damage.

The modem defaults to Command Mode on power-up.

### 1.2 NMEA0183 Protocol Standard

The Sealink protocol follows the NMEA0183 text-based format with proprietary extensions. All messages are ASCII, start with `$`, use comma separators, and end with `*` + two-digit hex checksum + `<CR><LF>`.

**Sentence example**:
`$PUWV0,1,0*36<CR><LF>`

**Structure**:
- `$` – sentence start  
- `P` – Proprietary  
- `UWV` – manufacturer identifier
- Sentence identifier (e.g. `0`, `2`, etc.)  
- `,` – parameter separator  
- `*` – checksum separator  
- `hh` – two-digit hex checksum (XOR of all bytes from after `$` to before `*`)  
- `<CR><LF>` – end of sentence (hex 0x0D 0x0A)

## 2. Sealink Commands & Responses

All sentences use the `$PUWV` prefix.

### 2.1 ACK Response
Device acknowledgement.

**Format**: `$PUWV0,cmdID,errCode*hh<CR><LF>`

| Field | Description |
|---|---|
| cmdID | ID of the incoming sentence causing this ACK |
| errCode  | Error code (see 4.1 Error Codes) |

### 2.2 Settings Write
Write new configuration settings.

**Format**: `$PUWV1,txChID,rxChID,salinityPSU,isCmdMode,isACKOnTXFinished,gravityAcc*hh<CR><LF>`

| Field | Description |
|---|---|
| txChID | Transmit code channel ID (0–19) |
| rxChID | Receive code channel ID (0–19) |
| salinityPSU | Water salinity in PSU (e.g. 0 for fresh, 35 for seawater) |
| isCmdMode | 1 = Command mode by default, 0 = Command mode by pin |
| isACKOnTXFinished | 1 = ACK sent after TX buffer empty, 0 = no ACK |
| gravityAcc | Local gravity acceleration (m/s², typical 9.77–9.84) |

### 2.3 Remote Code Request
Send a short command to a remote modem.

**Format**: `$PUWV2,txChID,rxChID,rcCmdID*hh<CR><LF>`

| Field | Description |
|---|---|
| txChID | Transmit code channel ID |
| rxChID | Receive code channel ID for the request |
| rcCmdID | Remote command ID (see 4.2 Remote Command IDs) |

### 2.4 Remote Code Response
Reply from remote modem.

**Format**: `$PUWV3,txChID,rcCmdID,propTime,MSR[,Value][,Azimuth]*hh<CR><LF>`

| Field | Description |
|---|---|
| txChID | Transmit code channel used |
| rcCmdID | Echo of requested command ID |
| propTime  | Propagation time in seconds (one-way) |
| MSR | Mean signal ratio (dB) |
| Value | Requested value (e.g. depth, temperature) |
| Azimuth | Horizontal angle of arrival (USBL models only) |

### 2.5 Remote Timeout
No reply from remote modem.

**Format**: `$PUWV4,txChID,rcCmdID*hh<CR><LF>`

| Field | Description |
|---|---|
| txChID | Transmit code channel used |
| rcCmdID | Requested command ID |

### 2.6 Remote Asynchronous Input
Incoming message from remote modem.

**Format**: `$PUWV5,rcCmdID,MSR[,Azimuth]*hh<CR><LF>`

| Field | Description |
|---|---|
| rcCmdID | Command ID (see 4.2) |
| MSR | Mean signal ratio (dB) |
| Azimuth | Horizontal angle of arrival (USBL models only) |

### 2.7 Ambient Data Configuration
Configure automatic transmission of ambient parameters and supply voltage.

**Format**: `$PUWV6,isSaveToFlash,PeriodMs,IsPressure,IsTemperature,IsDepth,IsVCC*hh<CR><LF>`

| Field | Description |
|---|---|
| isSaveToFlash | 1 = save to flash, 0 = do not save |
| PeriodMs | Output period (ms): 0 = disabled, 1 = tandem, 500–60000 = timed |
| IsPressure | 1 = enable pressure output, 0 = disable |
| IsTemperature | 1 = enable temperature output, 0 = disable |
| IsDepth | 1 = enable depth output, 0 = disable |
| IsVCC | 1 = enable supply voltage output, 0 = disable |

### 2.8 Ambient Data Output
Ambient parameters and supply voltage readings.

**Format**: `$PUWV7,Pressure_mBar,Temperature_C,Depth_m,VCC_V*hh<CR><LF>`

| Field | Description |
|---|---|
| Pressure_mBar | Pressure in millibars |
| Temperature_C | Temperature in °C |
| Depth_m | Depth in meters |
| VCC_V | Supply voltage in volts |

### 2.9 Device Information Request
Request device information.

**Format**: `$PUWV?,reserved*hh<CR><LF>`

| Field | Description |
|---|---|
| reserved  | Set to 0 |

### 2.10 Device Information
Device information response.

**Format**: `$PUWV!,serialNumber,systemMoniker,systemVersion,coreMoniker,coreVersion,acBaudrate,rxChID,txChID,maxChannels,styPSU,isPTS,isCmdMode*hh<CR><LF>`

| Field | Description |
|---|---|
| serialNumber | Device serial number |
| systemMoniker | System name |
| systemVersion | System version |
| coreMoniker | Communication subsystem name |
| coreVersion | Communication subsystem version |
| acBaudrate | Acoustic channel baud rate (bit/s) |
| rxChID | Receive code channel ID |
| txChID | Transmit code channel ID |
| maxChannels | Total number of code channels |
| styPSU | Salinity setting (PSU) |
| isPTS | 1 = pressure/temperature sensor present |
| isCmdMode | 1 = Command mode by default |

### 2.11 Packet Mode Settings Read
Read current packet mode settings. The modem responds with IC_D2H_PT_SETTINGS.

**Format**: `$PUWVD,reserved*hh<CR><LF>`

| Field | Description |
|---|---|
| reserved  | Set to 0 |

### 2.12 Packet Mode Settings
Current packet mode configuration.

**Format**: `$PUWVE,isPTMode,ptLocalAddress*hh<CR><LF>`

| Field | Description |
|---|---|
| isPTMode | 1 = packet mode enabled, 0 = disabled |
| ptLocalAddress | Local modem address (0–254) |

**Note**: Since firmware 1.20, packet mode is active whenever the modem is in Command Mode — no separate enable flag is required.

### 2.13 Packet Mode Settings Write
Set new packet mode settings. The modem responds with IC_D2H_PT_SETTINGS.

**Format**: `$PUWVF,isSaveToFlash,isPTMode,ptLocalAddress*hh<CR><LF>`

| Field | Description |
|---|---|
| isSaveToFlash | 1 = save to flash, 0 = do not save |
| isPTMode | 1 = enable packet mode, 0 = disable |
| ptLocalAddress  | Local modem address (0–254) |

**Note**: isPTMode is legacy (firmware 1.20+ ignores it — Command Mode enables packet mode automatically).

### 2.14 Packet Send
Send a data packet in packet mode.

**Format**: `$PUWVG,target_ptAddress,maxTries,dataPacket*hh<CR><LF>`

| Field | Description |
|---|---|
| target_ptAddress | Destination address (0–254 unicast, 255 broadcast) |
| maxTries | Maximum retransmission attempts (0–255; empty = default 255) |
| dataPacket | Hex bytes with `0x` prefix (e.g. `0x313233` for “123”). Max 64 bytes. Empty = cancel current transfer. |

### 2.15 Packet Failed
Transmission failed (max tries exceeded or other error).

**Format**: `$PUWVH,target_ptAddress,maxTries,dataPacket*hh<CR><LF>`

| Field | Description |
|---|---|
| target_ptAddress | Destination address |
| maxTries | Number of attempts made |
| dataPacket | Hex bytes sent (same as request) |

### 2.16 Packet Delivered
Packet successfully delivered with acknowledgement.

**Format**: `$PUWVI,target_ptAddress,maxTries[,azimuth],dataPacket*hh<CR><LF>`

| Field | Description |
|---|---|
| target_ptAddress | Destination address |
| maxTries | Number of attempts made |
| azimuth | Horizontal angle of arrival (USBL models only; empty otherwise) |
| dataPacket | Hex bytes sent (same as request) |

### 2.17 Packet Received
Incoming packet from another modem.

**Format**: `$PUWVJ,sender_ptAddress[,azimuth],dataPacket*hh<CR><LF>`

| Field | Description |
|---|---|
| sender_ptAddress | Sender address (0–254) |
| azimuth | Horizontal angle of arrival (USBL models only; empty otherwise) |
| dataPacket | Received hex bytes (max 64) |

### 2.18 Remote Request (Logical Addressing)
Request a parameter from a remote modem using logical addressing.

**Format**: `$PUWVK,target_ptAddress,dataID*hh<CR><LF>`

| Field | Description |
|---|---|
| target_ptAddress | Remote modem address (0–254) |
| dataID | Requested parameter: 0 = depth, 1 = temperature, 2 = supply voltage |

### 2.19 Remote Timeout (Logical Addressing)
No response to logical-addressed remote request.

**Format**: `$PUWVL,target_ptAddress,dataID*hh<CR><LF>`

| Field | Description |
|---|---|
| target_ptAddress | Remote modem address |
| dataID | Requested parameter ID |

### 2.20 Remote Response (Logical Addressing)
Response to logical-addressed remote request.

**Format**: `$PUWVM,target_ptAddress,dataID,dataValue,pTime[,azimuth]*hh<CR><LF>`

| Field | Description |
|---|---|
| target_ptAddress | Remote modem address |
| dataID | Requested parameter ID |
| dataValue | Returned value (e.g. depth in m, temp in °C, voltage in V) |
| pTime | Propagation time in seconds |
| azimuth | Horizontal angle of arrival (USBL models only; empty otherwise) |

### 2.21 Incremental Data Configuration (USBL models only)
Configure output of pitch and roll data.

**Format**: `$PUWV8,isSaveToFlash,PeriodMs*hh<CR><LF>`

| Field | Description |
|---|---|
| isSaveToFlash | 1 = save to flash, 0 = do not save |
| PeriodMs | Output period (ms): 0 = disabled, 1 = tandem, 500–60000 = timed |

### 2.22 Incremental Data Output (USBL models only)
Pitch and roll readings.

**Format**: `$PUWV9,reserved,Pitch,Roll*hh<CR><LF>`

| Field | Description |
|---|---|
| reserved  | Reserved (empty) |
| Pitch | Device pitch in degrees |
| Roll | Device roll in degrees |

## 3. Operating Modes

### 3.1 Transparent Channel Mode  
In Transparent mode, all data from the host is sent unchanged over the acoustic channel and received unchanged by another modem on the same code channel.

### 3.2 Command Mode  
Command mode allows configuration, ranging, and advanced control. Modems analyze incoming data only in this mode.  
- Default on power-up  
- Can be set permanently via Settings Write (isCmdMode = 1)  
- SVC/CMD pin (XP5 Pin 3) becomes a strobe output for Tx/Rx timing

### 3.3 Packet Mode  
Packet mode enables reliable data transfer up to 64 bytes, including arbitrary data, with guaranteed delivery and acknowledgement.  
- Active automatically in Command Mode (no separate enable needed since firmware 1.20+)  
- Supports 255 logical addresses (0–254 unicast, 255 broadcast)  
- See commands 2.11–2.20

## 4. Identifiers

### 4.1 Error Codes

| Code | Value | Description |
|---|---|---|
| LOC_ERR_NO_ERROR | 0 | Request accepted |
| LOC_ERR_INVALID_SYNTAX | 1 | Syntax error |
| LOC_ERR_UNSUPPORTED | 2 | Request not supported |
| LOC_ERR_TRANSMITTER_BUSY | 3 | Transmitter busy |
| LOC_ERR_ARGUMENT_OUT_OF_RANGE| 4 | Parameter out of range |
| LOC_ERR_INVALID_OPERATION | 5 | Invalid operation |
| LOC_ERR_UNKNOWN_FIELD_ID | 6 | Unknown field ID |
| LOC_ERR_VALUE_UNAVAILABLE | 7 | Value not available |
| LOC_ERR_RECEIVER_BUSY | 8 | Receiver busy |
| LOC_ERR_TX_BUFFER_OVERRUN | 9 | TX buffer overrun |
| LOC_ERR_CHKSUM_ERROR | 10 | Checksum error |
| LOC_ACK_TX_FINISHED | 11 | TX buffer empty |
| LOC_ACK_BEFORE_STANDBY | 12 | Entering standby |
| LOC_ACK_AFTER_WAKEUP | 13 | Exited standby |
| LOC_ERR_SVOLTAGE_TOO_HIGH | 14 | Supply voltage too high |

### 4.2 Remote Command IDs

| Command | Value | Description |
|---|---|---|
| RC_PING | 0 | Ping |
| RC_PONG | 1 | Pong |
| RC_DPT_GET | 2 | Get remote depth |
| RC_TMP_GET | 3 | Get remote temperature |
| RC_BAT_V_GET | 4 | Get remote battery voltage |
| RC_ERR_NSUP | 5 | Request not supported |
| RC_ACK | 6 | Request accepted |
| RC_USR_CMD_000–007  | 7–14  | User-defined commands |
| RC_MSG_ASYNC_IN | 16 | Incoming transparent message |

## 5. Appendix

### 5.1 Command Mode Examples  
- Examples use correct checksums and <CR><LF> terminators. Replace `hh` with actual calculated checksum.
- Examples use "<<" to indicate outbound messages/querries and ">>" to indicate inbound messages/responses.

#### **5.1.1 Example 1 – Requesting Device Information**  

`<< $PUWV?,0*27<CR><LF>`

`>> $PUWV!,3A001E000E51363437333330,SEALINK,1.00,SEALINK_CORE,1.01,9600,0,0,20,35.0,1,1*XX<CR><LF>`

**Explanation**:  

- PUWV? = IC_H2D_DINFO_GET  
- Response includes serial number, system/core versions, baud rate, channel IDs, salinity, sensor presence, and Command Mode status.

#### **5.1.2 Example 2 – Requesting Remote Depth**  

`<< $PUWV2,0,0,2*28<CR><LF>`

`>> $PUWV0,2,036<CR><LF>` (ACK: request accepted, no error)

`>> $PUWV3,0,2,0.667,25.40,12.34XX<CR><LF>` (response: propTime=0.667 s, depth=12.34 m)

**Explanation**:  

- PUWV2 = IC_H2D_RC_REQUEST  
- 2 = RC_DPT_GET  
- Response: propagation time (s), signal quality (MSR in dB), and remote depth (m)

#### **5.1.3 Example 3 – Setting up the Ambient Data Configuration**

`<< $PUWV6,1,1000,1,1,1,1*03<CR><LF>`

`>> $PUWV0,6,032<CR><LF>` (ACK: request accepted, no error)

`>> $PUWV7,1025.2,29.9,-0.014,5.018<CR><LF>`  (periodic ambient data)

`>> $PUWV7,1026.3,29.9,-0.002,5.0*1D<CR><LF>`  (next reading)

**Explanation**:  

- PUWV6 = IC_H2D_AMB_DTA_CFG  
- 1 = save to flash  
- 1000 = 1-second interval  
- 1,1,1,1 = enable pressure, temperature, depth, VCC  
- PUWV7 = IC_D2H_AMB_DTA (pressure in mBar, temperature in °C, depth in m, VCC in V)

#### **5.1.4 Example 4 – Enabling Packet Mode**  

`<< $PUWVF,1,1,0*5E<CR><LF>`

`>> $PUWVE,1,0*40<CR><LF>`

**Explanation**:  

- PUWVF = IC_H2D_PT_SETTINGS_WRITE  
- 1 = save to flash  
- 1 = enable packet mode  
- 0 = local modem address  
- PUWVE = IC_D2H_PT_SETTINGS (confirms packet mode enabled, address 0)

**Note**: Since firmware 1.20+, packet mode is active in Command Mode — no separate enable required.

#### **5.1.5 Example 5 – Sending a Packet in Packet Mode and Receiving Acknowledgement**  

`<< $PUWVG,0,8,0x313233*2C<CR><LF>`

`>> $PUWV0,G,043<CR><LF>` (ACK: request accepted, no error)

`>> $PUWVI,0,1,,0x31323307<CR><LF>` (packet delivered successfully)
  
**Explanation**:  

- PUWVG = IC_H2D_PT_SEND  
- 0 = target address  
- 8 = max attempts  
- 0x313233 = hex bytes for "123"  
- PUWVI = IC_D2H_PT_DLVRD (0 = target, 1 = attempts, empty = no azimuth)

#### **5.1.6 Example 6 – Receiving an Incoming Packet**  

`>> $PUWVJ,42,,0x48656C6C6F*XX<CR><LF>`

**Explanation**:  

- PUWVJ = IC_D2H_PT_RCVD  
- 42 = sender address  
- (empty) = no azimuth  
- 0x48656C6C6F = hex bytes for "Hello"  

No host action required — incoming packet is delivered automatically.

#### **5.1.7 Example 7 – Requesting Remote Temperature (Logical Addressing)**  

`<< $PUWVK,10,1*XX<CR><LF>`

`>> $PUWVM,10,1,28.50,0.667,XX<CR><LF>` (success)

`>> $PUWVL,10,1XX<CR><LF>` (timeout)

**Explanation**:  

- PUWVK = IC_H2D_PT_ITG  
- 10 = target address  
- 1 = dataID (temperature)  
- PUWVM = IC_D2H_PT_ITG_RESP (temperature 28.50 °C, propTime 0.667 s)  
- PUWVL = IC_D2H_PT_ITG_TMO (timeout)

#### **5.1.8 Example 8 – Enabling Automatic Ambient Data Output (1-second interval)**  

`<< $PUWV6,1,1000,1,1,1,1*03<CR><LF>`

`>> $PUWV0,6,032<CR><LF>` (ACK: request accepted, no error)

`>> $PUWV7,1025.2,29.9,-0.014,5.018<CR><LF>` (periodic output)

`>> $PUWV7,1026.3,29.9,-0.002,5.0*1D<CR><LF>`

**Explanation**:  

- PUWV6 = IC_H2D_AMB_DTA_CFG  
- 1 = save to flash  
- 1000 ms interval  
- 1,1,1,1 = enable pressure, temperature, depth, VCC

#### **5.1.9 Example 9 – Requesting Device Information (Alternative Syntax)**  

`<< $PUWV?,0*27<CR><LF>`

`>> $PUWV!,3A001E000E51363437333330,SEALINK,1.00,SEALINK_CORE,1.01,9600,0,0,20,35.0,1,1*XX<CR><LF>`

**Explanation**:  

- Same as 5.1.1 — included here for completeness. Shows legacy syntax still works.

### 5.2 Configuration Recipes

#### 1. **Set default settings (fresh water, Command mode disabled)**  
`$PUWV1,0,0,0.0,0,0,9.8067*XX<CR><LF>`

#### 2. **Enable Command mode by default, seawater salinity**  
`$PUWV1,0,0,35.0,1,0,9.8067*XX<CR><LF>`

#### 3. **Disable automatic ambient data output**  
`$PUWV6,0,0,0,0,0,0*32<CR><LF>`

#### 4. **Enable ambient data every 5 seconds (pressure + temperature only)**  
`$PUWV6,0,5000,1,1,0,0*XX<CR><LF>`

#### 5. **Request local depth (basic)**  
`$PUWV2,0,0,2*28<CR><LF>`

(Checksums must be calculated correctly before sending.)

---
Questions or support? Contact DiveNET: support@divenetgps.com
Last updated: March 2026

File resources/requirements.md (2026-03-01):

# DiveNET: Sealink-OEM - Requirements

## 1. Barebones operation

The modem can operate interely independetly as a remote responder able to receive and respond to standard command requests.  
To operate the modem as a remote responder in minimum configuration:  

- Connect the transducer to connector XP1 (OUT)
- Connect a +12-14V power supply to connector XP2 (POWER)

References: Sealink-OEM technical drawing; pinout diagram  

## 2. Manual control (send commands, read results)

For manual control, at least one modem must be connected to a serial interface to act as the "host" device and send command requests as needed.
   
- Transducer connected to XP1  
- Main power to XP2 (+12-14V)
- Serial connection to XP5 (serial to USB adapter or direct UART pins)  
- Default settings: 9600 8N1 (9600 speed, 8 data bits, no parity, 1 stop bit)  

Easy tools that work right away (no extra install):  

- Windows: PuTTY or Tera Term  
- Mac: CoolTerm  
- Linux: minicom or screen  

Tip: On Windows, find your COM port in Device Manager → Ports (COM & LPT).

For hardware projects, Arduino or Raspberry Pi can also connect directly to XP5 pins for manual control.

## 3. Automated control / custom features
   
For scripting, logging, or integration, any language that can open a serial port at 9600 8N1 works.

We recommend Python:  

- Install Python (free from python.org) with `pyserial` package 
- Use our sample Python script for initial testing and familiarization — just change the port name and run.

Other options:  
- C# (Windows apps)  
- Arduino or Raspberry Pi (for embedded projects — use serial libraries like Serial or pyserial)

Questions? Write to support@divenetgps.com.

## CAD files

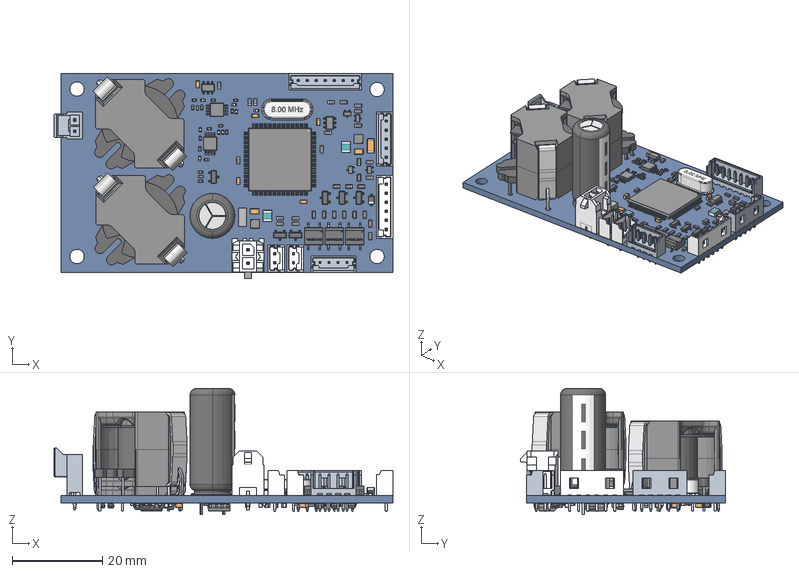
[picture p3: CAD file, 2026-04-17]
product/integrations/Sealink-OEM.step
75.1 x 45.3 x 28.0 mm
Board
SC?89 x 7
SOD-123 x 2
RM8_without_center_hole x 4
Скоба x 4
Coil_Former_(squared_pin,_pins_1,_12_are_trimmed) x 2
SOD-323 x 6
Molex_53253-0670
Molex_53253-0270 x 2
SOT95P280X145-6N_(MO-178-AB) x 2
RESC1608x50N x 44
CAPC1608X10N x 20
User_Library-sot23-1 x 6
SOIC-8_(MS-012-AA) x 2
4-lead_SOP_v4 x 3
MSOP-8_(MO-187-AA) x 2
Extruded x 88
CAPC3216X18N x 2
INDC2520X12N x 2
CAPC2012X11N x 2
8WSON_(MO-229-W2020) x 2
CAPC1608X05N x 2
EEU-FR1V821LB
LQFP-100_(MS-026-BED)
SC70_(MO-203-AB) x 2
HC49_US_8_MHz
Molex_43045-0212

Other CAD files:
product/integrations/Sealink-OEM.stl

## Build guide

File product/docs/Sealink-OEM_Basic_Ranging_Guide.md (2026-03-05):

# DiveNET: Sealink-OEM - Basic Ranging Guide (UART)

This guide explains how to perform basic range (distance) measurements using the Sealink-OEM acoustic modem over a serial (UART) interface. The system uses two-way travel time (propagation time) to calculate distance between two units.

## Key Principle

The Sealink-OEM measures the acoustic propagation time from a ping request to the response.  
The reported `propTime` is the **one-way** propagation time in seconds (from initiator to responder).

Distance is calculated as:

`range (m) = propTime (seconds) × sound_speed (m/s)`

- No further division is needed — the modem already computes the one-way time internally.
- Default sound speed used in examples: 1500 m/s (typical for seawater at ~20°C, moderate salinity).
- Real-world accuracy is typically ±0.15–0.5 m depending on sound speed precision and environmental conditions.

## 1. Requirements

### General Requirements
- At least two Sealink-OEM units powered and at least one connected via UART (9600 baud, 8N1, 3.3 V logic) for serial communication with a host system.
- Units must be on the same code channel (`txChID` and `rxChID` typically both 0 by default; configurable via protocol commands).
- Python environment with `pyserial` package installed on host machine.
  - **Note on XP5 pin 3 (`SVC/CMD`): This pin functions as a digital strobe output for transmit/receive events. It can be used by external systems for independent ToF timing. It does not improve nominal precision. No user action is required for normal UART protocol operation.**

### Dryland functional testing
- Place transducers within six inches of each other.
- **Note: Dryland operation is not designed to support payload data integrity! It is useful for functional testing only!**

### Water trials
- Devices positioned inside direct line of sight (LoS) and within maximum acoustic range (1 km or 3 km depending on transducer option).
- Supportive testing conditions: preferably open, calm waters; transducers stationary and approximately level; at least 3 m to both surface and bottom; and separated from adjacent large reflective surfaces.

## 2. Manual Ranging (via Serial Terminal)

Use any serial terminal (PuTTY, Tera Term, screen, minicom, etc.) at 9600 8N1.

### Step-by-step Example

**1. Connect to the local (initiator) unit via UART.**

**2. Send a ping request:**

`$PUWV2,0,0,0*2A<CR><LF>`

   - `0` = `txChID` (transmit channel)
   - `0` = `rxChID` (receive channel)
   - `0` = `rcCmdID` (remote command ID: 0 for ping)
   - `*2A` = example checksum (NMEA XOR of bytes between $ and *)

Note: The ping command does not include a target address. Units must be pre-configured with matching channels.

**3. Immediate acknowledgment from local modem (ACK):**

Typical ACK format:
`$PUWV0,cmdID,errCode*checksum<CR><LF>`

Example:
`$PUWV0,2,0*XX<CR><LF>`

   - `cmdID` = `2` (for `$PUWV2`)
   - `errCode` = `0` (no error; see protocol for other codes)

If `errCode` ≠ `0`, look up error code (e.g., invalid syntax, transmitter busy).

**4. Wait for response from the remote unit (automatic reply if in range and listening):**

Typical response format:
`$PUWV3,txChID,rcCmdID,propTime,MSR,value,azimuth*checksum<CR><LF>`

Example:
`$PUWV3,0,0,0.002489,22.75,,*1B<CR><LF>`

   - `propTime` = one-way propagation time in seconds
   - `MSR` = mean main lobe to side-peak ratio in dB (signal quality indicator)

**5. Calculate range:**

`range ≈ 0.002489 × 1500 = 3.7335 m`

## 3. Automated Ranging with Python Script

The repo currently includes a [basic ranging script](../resources/uart-getRange.py).

This script:

- Opens a serial port (via `--port` argument or interactive prompt)
- Sends a single ping request using sentence `$PUWV2,0,0,0*2A`
- Waits for and parses a `$PUWV3` sentence response
- Calculates sound speed from user inputs (depth, temperature, salinity)
- Prints propagation time and calculated slant range

Basic usage (from repository root):

1. Run: `python resources/uart-getRange.py`
2. Enter prompted values (port, channels, depth, temperature, salinity), or provide them as CLI arguments.
3. Observe the printed propagation time and range (or error if no response).

Example with explicit arguments:
`python resources/uart-getRange.py --port COM3 --tx 0 --rx 0 --test ping --depth 5 --temp 15 --salinity 35`

Example output (if successful):
`Range: 3733.5 m`

**Note: The script is designed for basic range testing only. For improved accuracy, use measured local environmental values and average multiple runs.**

## 4. Basic Ranging with Sealink-OEM Utility App

The Sealink-OEM Utility app can run the same basic ping/ranging workflow without command-line entry.

- Set serial port, channels, and environmental values directly in the app fields.
- Select `ping` and run the command.
- Review propagation time and calculated slant range in the app output panel.

See [Sealink-OEM Utility App Guide](Sealink-OEM_Utility_App_Guide.md) for full app workflow details.

## 5. Sound Speed Compensation Table

Sound speed varies with temperature, salinity, and depth. Use these approximate values or measure on-site.

| Water Type | Temp (°C) | Salinity (ppt) | Depth (m) | Sound Speed (m/s) |
|---|---|---|---|---|
| Freshwater | 20 | 0 | 0 | 1482 |
| Seawater (typical)  | 20 | 35 | 0 | 1522 |
| Seawater | 10 | 35 | 0 | 1490 |
| Seawater | 25 | 35 | 0 | 1534 |
| Deep ocean (avg) | 4 | 35 | 1000+ | 1480–1550 |

## 6. Tips for Reliable Ranging

- Max range — Up to 1,000 m (SW-T100 transducer) / 3,000 m (SW-T200/300 transducers) in supportive conditions (clear, calm, open water, low noise).
- Shallow water / multipath — Use averaging (run script multiple times); avoid strong surface/bottom reflections or large reflective surfaces.
- Signal quality (MSR) — Higher dB values indicate cleaner link.
- No response? — Check: matching channels? Powered on? In water? Transducer connected?
- Power saving — Units only transmit during pings; keep Rx duty cycle low.

## 7. Troubleshooting Common Issues

- No `$PUWV3` response → May receive `$PUWV4` (timeout); check acoustic path, verify remote listening, confirm channel match.
- Inconsistent ranges → Environmental factors; repeat measurement and average manually.
- Checksum errors → Ensure terminal/script computes NMEA XOR correctly.
- Error in ACK (`$PUWV0`) → Check `errCode` (e.g., 3 = transmitter busy, 4 = out of range); resolve before retrying.

For advanced protocol commands (set/query channel/address, etc.), see [Sealink-OEM Communication Protocol](./Sealink-OEM_Communication_Protocol.md).

---
Questions or support? Contact DiveNET: support@divenetgps.com
Last updated: March 2026

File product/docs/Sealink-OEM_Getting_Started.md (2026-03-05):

# DiveNET: Sealink-OEM - Getting Started

## 1. Bare-bones Operation

The modem can operate independently as a remote responder able to receive and respond to standard command requests without a data interface to a host system. To operate the modem as a remote responder in minimum configuration:  

- Connect the transducer to connector XP1 (OUT)
- Connect a +12-14V power supply to connector XP2 (POWER)

## 2. Manual Control (Send Commands, Read Results)

For manual control, at least one modem must be connected to a serial interface to act as the "host" device and send command requests as needed.
   
- Transducer connected to XP1  
- Main power to XP2 (+12-14V)
- Serial connection to XP5 (serial to USB adapter or direct UART pins)  
- Default settings: 9600 8N1 (9600 speed, 8 data bits, no parity, 1 stop bit)  

Easy tools that work right away (no extra install):  

- Windows: PuTTY or Tera Term  
- Mac: CoolTerm  
- Linux: minicom or screen  

Tip: On Windows, find your COM port in Device Manager → Ports (COM & LPT).

For hardware projects, Arduino or Raspberry Pi can also connect directly to XP5 pins for manual control.

## 3. Automation and Integration

For scripting, logging, or system integration, any language that can open a serial port at `9600 8N1` can control Sealink-OEM.

Recommended first path (Python):

- Install Python `3.10+` from python.org.
- Install `pyserial`.
- Run the sample Python script first to verify communication.
- Common command options are `--port`, `--tx`, `--rx`, and `--test`.
- If an option is omitted, the script prompts for the missing value.

If you prefer interactive (GUI) operation:

- Use the Sealink-OEM Utility app and enter port/channel/environment values in the app fields.
- See [Sealink-OEM Utility App Guide](Sealink-OEM_Utility_App_Guide.md) for app workflows.

For virtual environment setup and CLI examples, see [Integrator Platform Guide](../integrations/PLATFORM_INTEGRATOR_GUIDE.md).

Other implementation options:
- C# (Windows applications)
- Arduino or Raspberry Pi (embedded projects using serial libraries)

## 4. References
- [Sealink-OEM technical drawing](Sealink-OEM_Technical_Drawing.pdf)
- [Connector pinout guide](Sealink-OEM_Pinout_and_Interface.md)
- [Communication protocol](Sealink-OEM_Communication_Protocol.md) 

## 5. Next steps

- For app-focused Windows operation, continue with [Sealink-OEM Utility App Guide](Sealink-OEM_Utility_App_Guide.md).
- For command details, use [Communication protocol](Sealink-OEM_Communication_Protocol.md).
- For range testing specifics, use [Basic Ranging Guide](Sealink-OEM_Basic_Ranging_Guide.md).

---
Questions or support? Contact DiveNET: support@divenetgps.com
Last updated: March 2026

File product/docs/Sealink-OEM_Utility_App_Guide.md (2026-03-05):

# DiveNET: Sealink-OEM Utility App Guide

This guide explains how to use the Sealink-OEM Utility app and when to use the integrator workflow.

## Minimum Host Requirements

### A) Sealink-OEM (Windows Utility Package)

- OS: Windows 10 or Windows 11 (64-bit)
- No Python installation required for `.exe` usage
- At least one available serial port (`COMx`) via USB-UART adapter or direct UART bridge
- Local file write access in the package folder (for launch scripts and logs)

### B) Sealink-Integrator-Pack (Integrator CLI Package)

- Python 3.10+ (3.10-3.14 validated)
- `pip` available for dependency install
- Packages from `resources/requirements.txt` (includes `pyserial`)
- Platform workflows:
	- Windows/Linux/macOS for Python CLI script usage
	- Raspberry Pi/Linux shell script usage under `integrations/raspberry-pi`
	- Arduino IDE for `integrations/arduino/SealinkOEM_Basic.ino`
- Detailed venv creation/activation commands are documented in `integrations/PLATFORM_INTEGRATOR_GUIDE.md`.

## 1. Scope

The Utility app is intended for:

- Initial product familiarization
- Basic command execution and response verification
- Essential functionality/performance checks

## 2. Windows Utility Workflow

In the Sealink-OEM package folder:

Main Files:

- `SealinkUtility.exe` (main app)
- `SealinkListener.exe` (test/demo listener)
- `run_utility.bat` (start utility only)
- `run_listener.bat` (start listener only)
- `run_all.bat` (start listener + utility)

Typical Use:

1. Connect hardware and identify COM port.
2. Start `run_utility.bat`.
3. Enter serial port, channels, and environmental parameters in the app.
4. Select command (`ping`, `device-info`, or `remote-depth`) and run.

## 3. Source Repository Workflow (Python, optional)

If you are working from the source repository (not a packaged download):

- Start utility: `launch_utility.bat`
- Start listener only: `launch_listener.bat`
- Start both windows: `start_all.bat`
- Quiet start: `start_all_quiet.bat`

Underlying script:

- `product/resources/sealink_utility.py`

## 4. Utility Inputs

Required/Typical Fields:

- Serial port (for example `COM3`)
- TX channel
- RX channel
- Depth (m)
- Temperature (°C)
- Salinity (PSU)
- Command selection

The app computes sound speed from environmental values and reports propagation time and slant range from responses.

## 5. Relationship to CLI Test Script

The Utility app wraps the same command logic used by:

- `product/resources/uart-getRange.py`

Use the script directly when CLI automation is preferred.

## 6. Troubleshooting

- Port open error: verify COM port and close other serial tools.
- No response: verify wiring, transducer connection, channel match, and acoustic path.
- Unstable results: collect multiple pings and average under stable conditions.

For protocol-level details, see [Sealink-OEM Communication Protocol](Sealink-OEM_Communication_Protocol.md).

---
Questions or support? Contact DiveNET: support@divenetgps.com
Last updated: March 2026

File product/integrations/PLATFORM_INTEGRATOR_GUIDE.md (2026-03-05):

# Sealink OEM Integrator Platform Guide

## Which package should you use?

Choose the package that matches your workflow.

### Package A: `Sealink-OEM` (Windows Utility package)
Use this package for normal Windows operation with the desktop utility.

This is the turnkey Windows Utility package with `.exe` binaries and `.bat` launchers for normal day-to-day use.

See `docs/Sealink-OEM_Utility_App_Guide.md` for app-specific usage details.

### Package B: `Sealink-Integrator-Pack` (Technical integration package)
Use this package if you are integrating on Raspberry Pi/Linux or Arduino.

This package covers Linux/Raspberry Pi and Arduino workflows in a single technical bundle.

## Python Environment Setup (Integrator CLI)

Run these commands from the `Sealink-Integrator-Pack` root folder.

### Windows (PowerShell)
```powershell
python -m venv .venv
.\.venv\Scripts\Activate.ps1
python -m pip install -r resources\requirements.txt
```

If PowerShell blocks script execution:
```powershell
Set-ExecutionPolicy -Scope CurrentUser RemoteSigned
```

### Linux / Raspberry Pi / macOS
```bash
python3 -m venv .venv
source .venv/bin/activate
python -m pip install -r resources/requirements.txt
```

### Basic CLI Validation
```bash
python resources/uart-getRange.py --port <PORT> --test ping --tx 0 --rx 0
```

Replace `<PORT>` with the host serial interface (for example `COM3` on Windows or `/dev/ttyUSB0` on Linux).

## Integrator targets included

### Raspberry Pi / Linux
Files:
- `resources/uart-getRange.py`
- `resources/requirements.txt`
- `integrations/raspberry-pi/run_sealink_cli.sh`

Quick start on Raspberry Pi:
```bash
cd integrations/raspberry-pi
chmod +x run_sealink_cli.sh
./run_sealink_cli.sh --port /dev/ttyUSB0 --test ping --tx 0 --rx 0
```

Notes:
- UART protocol is `9600 8N1`.
- For onboard UART (GPIO), port is commonly `/dev/serial0`.
- CLI is preferred for headless/system integration.

### Arduino / MCU
File:
- `integrations/arduino/SealinkOEM_Basic.ino`

What it does:
- Builds proper `$PUWV...*hh` checksum sentences.
- Sends device info request (`PUWV?,0`) and remote ping (`PUWV2,tx,rx,0`).
- Parses `PUWV3` propagation time and prints approximate range.

Hardware requirements:
- 3.3V UART logic compatible with Sealink-OEM.
- Board with a hardware UART connected to modem (example sketch uses `Serial1`).

## macOS support
There is no separate macOS desktop package.

For macOS, use the CLI workflow with the same steps shown for Linux.

---
Questions or support? Contact DiveNET: support@divenetgps.com
Last updated: March 2026

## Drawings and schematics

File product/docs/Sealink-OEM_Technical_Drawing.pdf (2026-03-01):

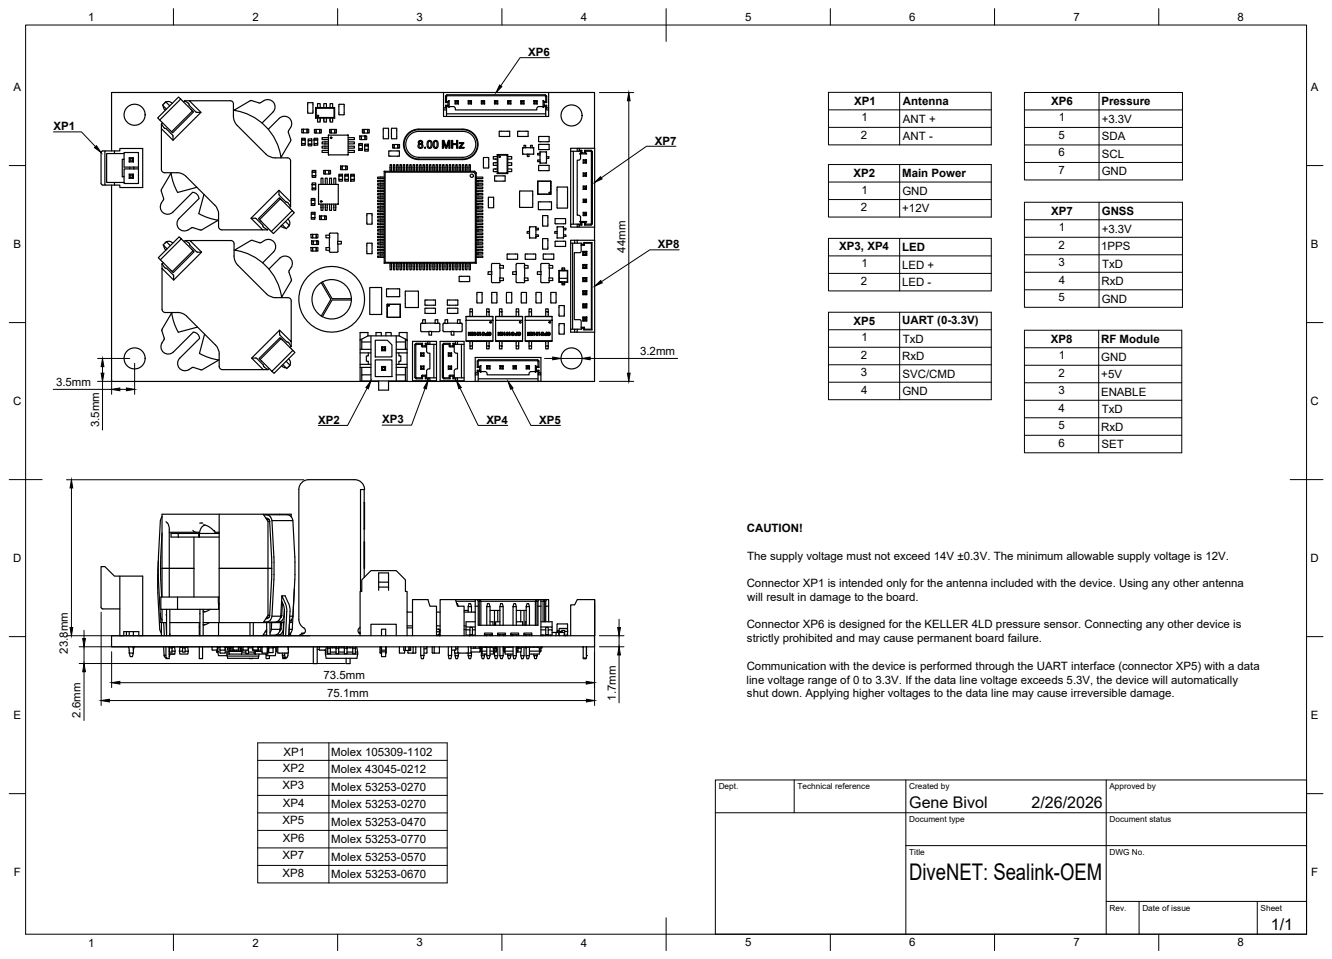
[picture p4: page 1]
Dept.; Technical reference; Created by; Approved by; Document type; Document status; Title; DWG No.; Rev.; Date of issue; Sheet; Gene Bivol; Molex 53253-0270; Molex 53253-0470; ANT +; ANT -; Main Power; LED; LED +; LED -; UART (0-3.3V); RF Module

1 | GND
2 | +12V

XP7 | GNSS
1 | +3.3V

4 | TxD
5 | RxD
6 | SET

The supply voltage must not exceed 14V ±0.3V. The minimum allowable supply voltage is 12V.

Connector XP1 is intended only for the antenna included with the device. Using any other antenna
will result in damage to the board.

Connector XP6 is designed for the KELLER 4LD pressure sensor. Connecting any other device is
strictly prohibited and may cause permanent board failure.

Communication with the device is performed through the UART interface (connector XP5) with a data
line voltage range of 0 to 3.3V. If the data line voltage exceeds 5.3V, the device will automatically
shut down. Applying higher voltages to the data line may cause irreversible damage.

XP1 | Molex 105309-1102
XP2 | Molex 43045-0212

XP6 | Molex 53253-0770
XP7 | Molex 53253-0570
XP8 | Molex 53253-0670

DiveNET: Sealink-OEM

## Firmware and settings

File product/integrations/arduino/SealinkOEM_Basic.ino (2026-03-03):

/*
  SealinkOEM_Basic.ino
  Minimal Arduino example for Sealink-OEM UART protocol.

  Hardware assumptions:
  - Board has Serial (USB debug) and Serial1 (hardware UART to modem)
  - Modem UART: 9600 8N1, 3.3V logic

  Wiring (example):
  - Arduino Serial1 TX -> Sealink RX
  - Arduino Serial1 RX -> Sealink TX
  - GND shared
*/

static const unsigned long RESPONSE_TIMEOUT_MS = 8000;

String buildSentence(const String &bodyWithoutDollar) {
  uint8_t checksum = 0;
  for (size_t i = 0; i < bodyWithoutDollar.length(); ++i) {
    checksum ^= (uint8_t)bodyWithoutDollar[i];
  }

  char hex[3];
  snprintf(hex, sizeof(hex), "%02X", checksum);

  String sentence = "$";
  sentence += bodyWithoutDollar;
  sentence += "*";
  sentence += hex;
  sentence += "\r\n";
  return sentence;
}

void sendSealink(const String &bodyWithoutDollar) {
  String full = buildSentence(bodyWithoutDollar);
  Serial1.print(full);
  Serial.print("TX -> ");
  Serial.print(full);
}

bool readLineFromSealink(String &line, unsigned long timeoutMs) {
  unsigned long start = millis();
  line = "";
  while (millis() - start < timeoutMs) {
    while (Serial1.available() > 0) {
      char c = (char)Serial1.read();
      if (c == '\n') {
        line.trim();
        return line.length() > 0;
      }
      line += c;
    }
  }
  return false;
}

void printRangeIfPUWV3(const String &line) {
  if (!line.startsWith("$PUWV3,")) {
    return;
  }

  int comma1 = line.indexOf(',');
  int comma2 = line.indexOf(',', comma1 + 1);
  int comma3 = line.indexOf(',', comma2 + 1);
  int comma4 = line.indexOf(',', comma3 + 1);

  if (comma3 < 0 || comma4 < 0) {
    Serial.println("RX parse: invalid PUWV3 format");
    return;
  }

  String tpStr = line.substring(comma3 + 1, comma4);
  float propagationSec = tpStr.toFloat();
  float distanceM = propagationSec * 1500.0f;

  Serial.print("RX propagation: ");
  Serial.print(propagationSec, 4);
  Serial.print(" s, approx range: ");
  Serial.print(distanceM, 1);
  Serial.println(" m");
}

void doPing(uint8_t txCh, uint8_t rxCh) {
  String body = "PUWV2," + String(txCh) + "," + String(rxCh) + ",0";
  sendSealink(body);

  String response;
  if (readLineFromSealink(response, RESPONSE_TIMEOUT_MS)) {
    Serial.print("RX <- ");
    Serial.println(response);
    printRangeIfPUWV3(response);
  } else {
    Serial.println("RX timeout waiting for ping response");
  }
}

void doDeviceInfo() {
  sendSealink("PUWV?,0");

  String response;
  if (readLineFromSealink(response, RESPONSE_TIMEOUT_MS)) {
    Serial.print("RX <- ");
    Serial.println(response);
  } else {
    Serial.println("RX timeout waiting for device info");
  }
}

void setup() {
  Serial.begin(115200);
  while (!Serial) {}

  Serial1.begin(9600);

  Serial.println("Sealink OEM Arduino example ready.");
  Serial.println("Commands over USB Serial monitor:");
  Serial.println("  i            -> device info");
  Serial.println("  p            -> ping tx=0 rx=0");
  Serial.println("  p <tx> <rx>  -> ping with channels");
}

void loop() {
  if (!Serial.available()) {
    return;
  }

  String cmd = Serial.readStringUntil('\n');
  cmd.trim();
  if (cmd.length() == 0) {
    return;
  }

  if (cmd == "i") {
    doDeviceInfo();
    return;
  }

  if (cmd == "p") {
    doPing(0, 0);
    return;
  }

  if (cmd.startsWith("p ")) {
    int firstSpace = cmd.indexOf(' ');
    int secondSpace = cmd.indexOf(' ', firstSpace + 1);
    if (secondSpace > firstSpace) {
      uint8_t tx = (uint8_t)cmd.substring(firstSpace + 1, secondSpace).toInt();
      uint8_t rx = (uint8_t)cmd.substring(secondSpace + 1).toInt();
      doPing(tx, rx);
      return;
    }
  }

  Serial.println("Unknown command. Use: i | p | p <tx> <rx>");
}

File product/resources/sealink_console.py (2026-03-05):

#!/usr/bin/env python3
"""Sealink OEM console scaffold.

This is a non-breaking scaffold for future console-first workflows.
Current release tooling remains unchanged while this module evolves.
"""

from __future__ import annotations

import argparse
import datetime as dt
import importlib.util
import json
import os
import shlex
import sys
import time
from dataclasses import asdict, dataclass
from typing import Any

from serial.tools import list_ports

try:
    import readline
except ImportError:
    readline = None


@dataclass
class ConsoleResult:
    ok: bool
    command: str
    message: str
    data: dict[str, Any] | None = None


def _print_result(result: ConsoleResult, as_json: bool) -> int:
    if as_json:
        print(json.dumps(asdict(result), indent=2))
    else:
        status = "OK" if result.ok else "ERROR"
        print(f"[{status}] {result.command}: {result.message}")
    return 0 if result.ok else 1


def _append_log_line(log_file: str | None, message: str) -> None:
    if not log_file:
        return
    parent = os.path.dirname(log_file)
    if parent:
        os.makedirs(parent, exist_ok=True)
    with open(log_file, "a", encoding="utf-8") as f:
        f.write(message + "\n")


def _debug_print(args: argparse.Namespace, message: str) -> None:
    if not getattr(args, "debug", False):
        return
    timestamp = dt.datetime.now().isoformat(timespec="seconds")
    line = f"{timestamp} [DEBUG] {message}"
    print(line, file=sys.stderr)
    _append_log_line(getattr(args, "log_file", None), line)


def _log_command_result(args: argparse.Namespace, result: ConsoleResult) -> None:
    log_file = getattr(args, "log_file", None)
    if not log_file:
        return
    payload = {
        "ts": dt.datetime.now().isoformat(timespec="seconds"),
        "command": result.command,
        "ok": result.ok,
        "message": result.message,
        "data": result.data,
    }
    _append_log_line(log_file, json.dumps(payload, ensure_ascii=True))


def _resolve_uart_helper_path() -> str:
    candidate_dirs = [os.path.dirname(os.path.abspath(__file__))]
    pyinstaller_temp_dir = getattr(sys, "_MEIPASS", None)
    if pyinstaller_temp_dir:
        candidate_dirs.insert(0, pyinstaller_temp_dir)

    checked_paths: list[str] = []
    for directory in candidate_dirs:
        direct_candidate = os.path.join(directory, "uart-getRange.py")
        nested_candidate = os.path.join(directory, "product", "resources", "uart-getRange.py")
        dir_wrapped_candidate = os.path.join(directory, "uart-getRange.py", "uart-getRange.py")

        for candidate in (direct_candidate, nested_candidate, dir_wrapped_candidate):
            checked_paths.append(candidate)
            if os.path.isfile(candidate):
                return candidate

    checked_display = "\n".join(checked_paths)
    raise FileNotFoundError(f"Unable to locate uart-getRange.py. Checked:\n{checked_display}")


def _load_uart_helpers() -> tuple[Any, Any, Any, Any]:
    module_path = _resolve_uart_helper_path()
    module_spec = importlib.util.spec_from_file_location("sealink_uart_helpers", module_path)
    if module_spec is None or module_spec.loader is None:
        raise ImportError(f"Unable to create module spec for helper script: {module_path}")

    helper_module = importlib.util.module_from_spec(module_spec)
    module_spec.loader.exec_module(helper_module)

    return (
        helper_module.serial,
        helper_module.calculate_nmea_checksum,
        helper_module.send_rc_ping,
        helper_module.read_response,
    )


SERIAL, CALCULATE_NMEA_CHECKSUM, SEND_RC_PING, READ_RESPONSE = _load_uart_helpers()
DEFAULT_PROFILE_PATH = os.path.join(os.path.expanduser("~"), ".sealink_console_profile.json")
DEFAULT_HISTORY_PATH = os.path.join(os.path.expanduser("~"), ".sealink_console_history")
COMMAND_ALIASES = {
    "lp": "list-ports",
    "di": "device-info",
    "ps": "profile-set",
    "sh": "shell",
}


def _open_serial(port: str, baud: int):
    return SERIAL.Serial(
        port=port,
        baudrate=baud,
        parity=SERIAL.PARITY_NONE,
        stopbits=SERIAL.STOPBITS_ONE,
        bytesize=SERIAL.EIGHTBITS,
        timeout=1,
    )


def _load_profile(path: str | None) -> dict[str, Any]:
    profile_path = path or DEFAULT_PROFILE_PATH
    if not os.path.isfile(profile_path):
        return {}
    try:
        with open(profile_path, "r", encoding="utf-8") as f:
            data = json.load(f)
        return data if isinstance(data, dict) else {}
    except Exception:
        return {}


def _save_profile(path: str | None, profile_data: dict[str, Any]) -> str:
    profile_path = path or DEFAULT_PROFILE_PATH
    parent = os.path.dirname(profile_path)
    if parent:
        os.makedirs(parent, exist_ok=True)
    with open(profile_path, "w", encoding="utf-8") as f:
        json.dump(profile_data, f, indent=2)
    return profile_path


def _resolve_port_and_baud(args: argparse.Namespace, profile: dict[str, Any]) -> tuple[str | None, int]:
    port = args.port or profile.get("default_port")
    baud = args.baud if args.baud is not None else int(profile.get("default_baud", 9600))
    return port, baud


def _normalize_command_alias(tokens: list[str], args_for_debug: argparse.Namespace | None = None) -> list[str]:
    if not tokens:
        return tokens
    cmd = tokens[0]
    mapped = COMMAND_ALIASES.get(cmd)
    if not mapped:
        return tokens
    if args_for_debug is not None:
        _debug_print(args_for_debug, f"alias expanded: {cmd} -> {mapped}")
    return [mapped, *tokens[1:]]


def _load_shell_history(path: str) -> None:
    if readline is None:
        return
    try:
        read_history = getattr(readline, "read_history_file", None)
        if os.path.isfile(path) and callable(read_history):
            read_history(path)
    except Exception:
        return


def _save_shell_history(path: str) -> None:
    if readline is None:
        return
    try:
        write_history = getattr(readline, "write_history_file", None)
        if callable(write_history):
            write_history(path)
    except Exception:
        return


def _read_first_nonempty_line(ser, timeout_sec: float) -> str | None:
    start = time.time()
    while time.time() - start < timeout_sec:
        line = ser.readline().decode("ascii", errors="ignore").strip()
        if line:
            return line
    return None
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

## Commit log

2026-02-21 Add UART basic range measurement script
2026-02-22 Upd README with UART ranging instructions
    Added detailed UART ranging instructions and command examples.
2026-03-01 Add Sealink-OEM pinout and interface documentation
    Added detailed pinout and interface information for the DiveNET Sealink-OEM board
2026-03-03 Docs: normalize tone in policy and landing text
2026-03-03 Docs: update ranging/getting-started for current utility input workflow
2026-03-05 release: cut v1.0.5
2026-04-17 +pcb step
    [Sealink-OEM.step]
2026-04-17 + stl file
    [Sealink-OEM.stl]
